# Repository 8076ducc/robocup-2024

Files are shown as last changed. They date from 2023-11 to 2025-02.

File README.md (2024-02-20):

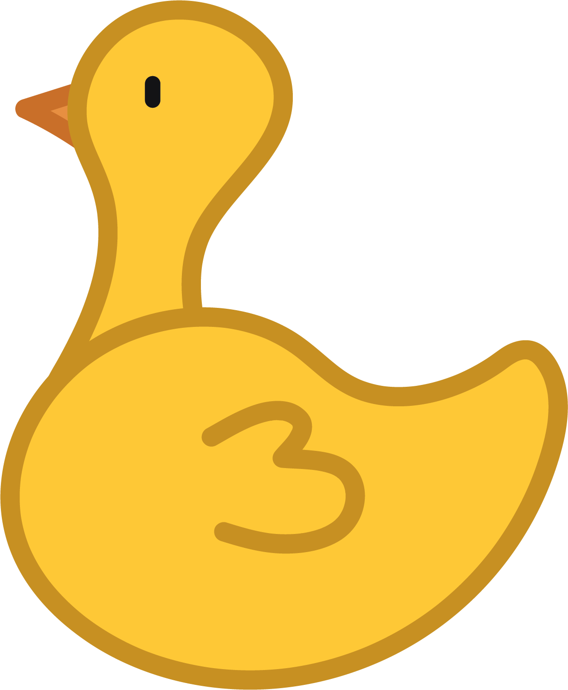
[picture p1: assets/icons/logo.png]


# ducc. Robotics: RoboCupJunior Soccer 2024

This repository contains ducc's working files and source code for the 2024 RoboCupJunior Soccer Open and Soccer Lightweight competition.

## About

ducc is a six-man team comprising Neo Hao Jun, Isaac Tan, Zhu Yunsong, Aidan Yeong, Oliver Zhao, and Ng Aaron from the Hwa Chong Robotics Club in Singapore.

## Technologies

This project was built with the following tools:

- Mechanical: Autodesk Fusion 360
- Electrical: KiCad
- Programming: PlatformIO

## Intellectual Property

### Copyright

© 2023, ducc. Robotics Competition Team.

While we have made every effort to abide by legal and ethical requirements when using works that we did not create, some may have been overlooked inadvertently. Please let us know and we will be happy to make the necessary arrangements.

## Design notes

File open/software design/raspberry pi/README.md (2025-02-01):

1. Get the dt-blob-bin file by running `sudo wget https://datasheets.raspberrypi.com/cmio/dt-blob-dualcam.bin -O /boot/dt-blob.bin` in the terminal.

2. Run `sudo nano /boot/firmware/config.txt` in the terminal, scroll down and add the following lines to the bottom of the file:
```
dtoverlay=imx708,cam0
dtoverlay=imx708,cam1
```

3. Run `libcamera-hello` in the terminal to determine if the cameras are detected.

4. Compile OpenCV from source; follow the guide [here](https://qengineering.eu/install-opencv-on-raspberry-64-os.html).

5. Install LCCV by following the instructions [here](https://github.com/8076ducc/lccv).

6. Create symbolic links by running the following commands in the terminal:
```bash
sudo ln -s /usr/local/include/opencv4/opencv2 /usr/local/include/opencv2
sudo ln -s /usr/include/libcamera/libcamera /usr/local/include/libcamera
```

7. Install wiringpi by following the guide [here](https://github.com/WiringPi/WiringPi).

8. In Geany, manage your build settings and configure it to compile via the following command:
```bash
sudo g++ -Wall -o "%e" "%f" -lopencv_core -lopencv_videoio -lopencv_highgui -lopencv_imgproc -lopencv_video -llccv -lwiringPi
```

9. Test Geany compilation by pressing the brown brick button in your desired file (e.g. `tracker.cpp`; don't compile in `threads.h` or some other header file) THEN run the code by clicking the airplane symbol. You may wish to use the function row keyboard shortcuts at your convenience.

10. Transfer the two files in the `systemctl` folder in this repository to the `/lib/systemd/system` folder on the Raspberry Pi.

11. Individually check that the services are working using the following commands:
```bash
sudo systemctl start configure-gpio.service
sudo systemctl status configure-gpio.service
sudo systemctl stop configure-gpio.service

sudo systemctl start tracker.service
sudo systemctl status tracker.service
sudo systemctl stop tracker.service
```

12. Enable both services to run on startup using the following commands:
```bash
sudo systemctl enable configure-gpio.service
sudo systemctl enable tracker.service
```

13. Run `sudo systemctl disable NetworkManager-wait-online.service` in the terminal.

Other notes:
- DO NOT 千万不要 plug or unplug the camera module while power is still connected. Shut the RPi down and unplug all power cables before doing anything with the camera module.
- Placing everything in the Desktop is a personal decision I made so that it's more convenient for me to open files when I VNC into the RPi. You might want to pull the entire repository directly into the RPi (I highly recomend that); in which case you should change the directories to the executables in the `configure-gpio.service` and `tracker.service` files.

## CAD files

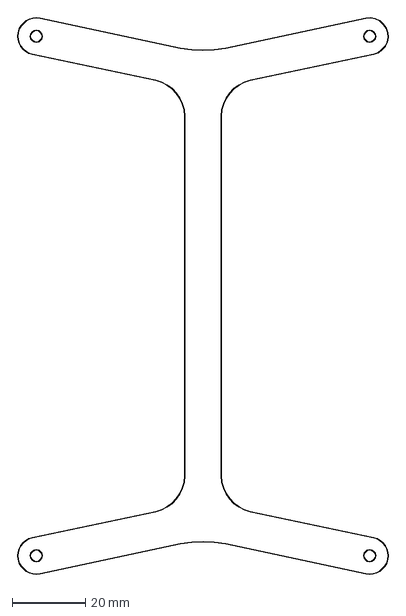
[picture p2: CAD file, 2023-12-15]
open/mechanical design/plates/handle/full drawing.dxf
101.7 x 152.3 mm

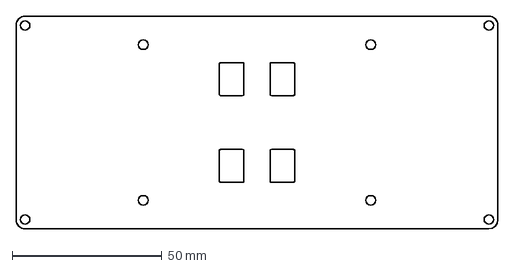
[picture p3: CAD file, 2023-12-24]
open/mechanical design/plates/layer 2.5/full drawing.dxf
161.0 x 71.0 mm

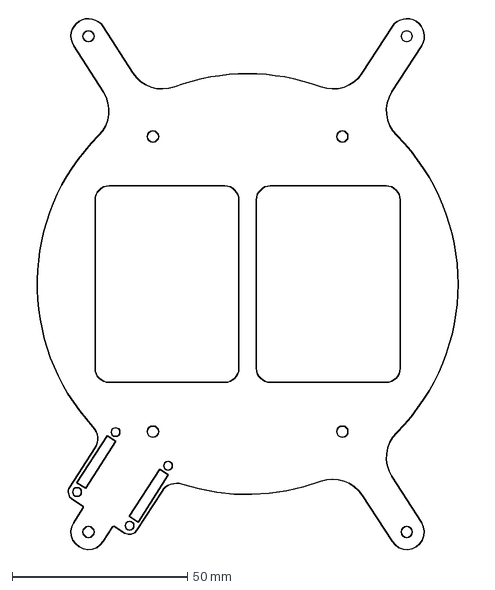
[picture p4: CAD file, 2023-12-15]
open/mechanical design/plates/layer 5/full drawing.dxf
131.8 x 152.2 mm

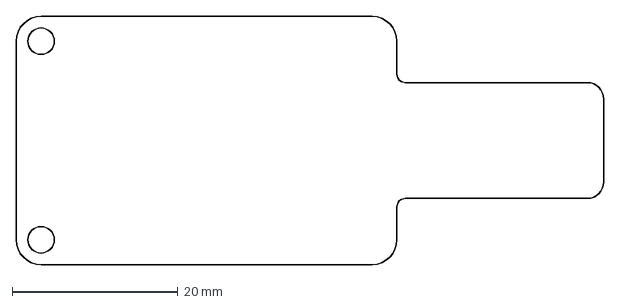
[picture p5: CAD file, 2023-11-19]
open/mechanical design/plates/driver/full outline.dxf
71.0 x 30.0 mm

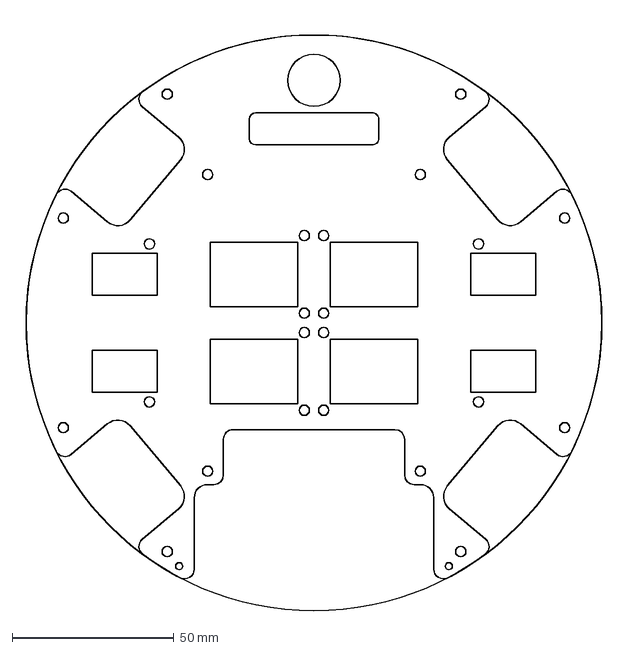
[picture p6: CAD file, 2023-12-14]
open/mechanical design/plates/layer 2/full drawing.dxf
184.2 x 183.8 mm

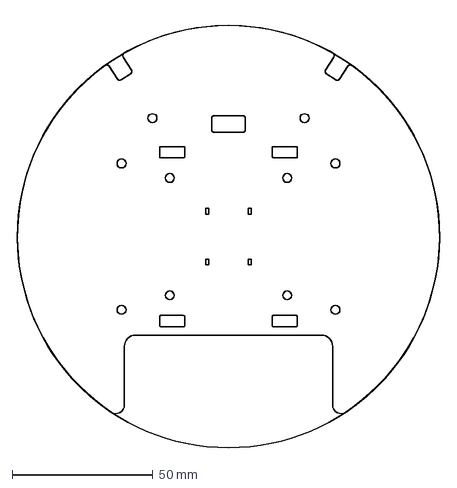
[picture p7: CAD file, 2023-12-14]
open/mechanical design/plates/layer 3/full drawing.dxf
150.9 x 153.3 mm

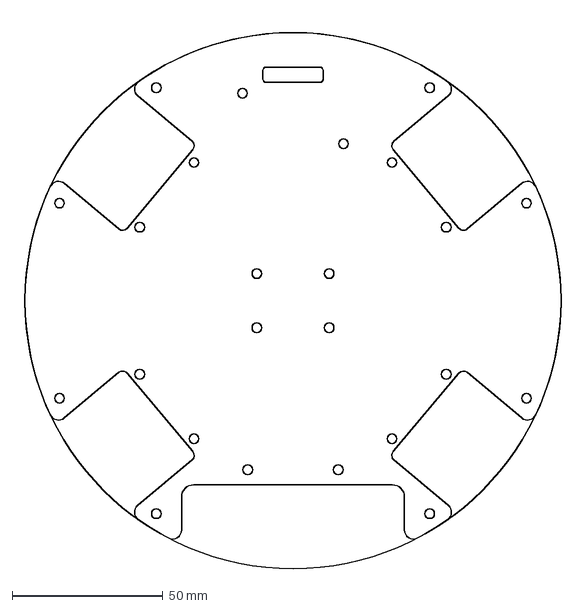
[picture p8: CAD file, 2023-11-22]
open/mechanical design/plates/layer 1/full drawing.dxf
183.7 x 183.4 mm

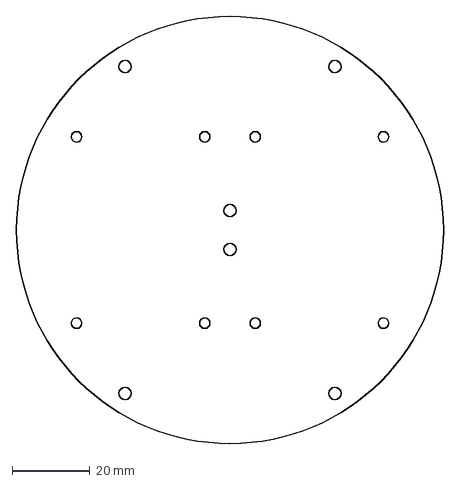
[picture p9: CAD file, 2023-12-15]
open/mechanical design/plates/layer 4/full drawing.dxf
110.0 x 110.0 mm

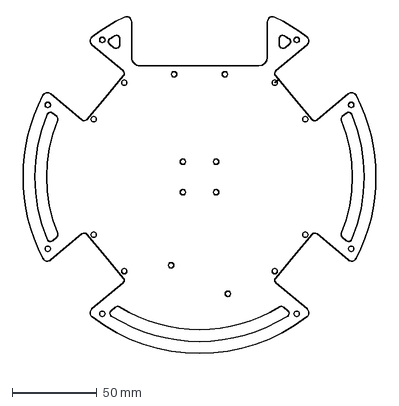
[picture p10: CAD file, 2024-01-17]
lightweight/layer1/lw layer1.dxf
215.8 x 205.7 mm

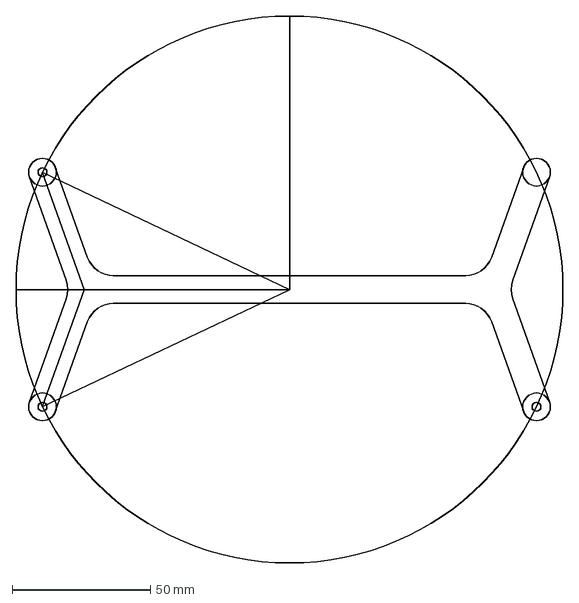
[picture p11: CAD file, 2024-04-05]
lightweight/lw handle.dxf
198.0 x 198.0 mm

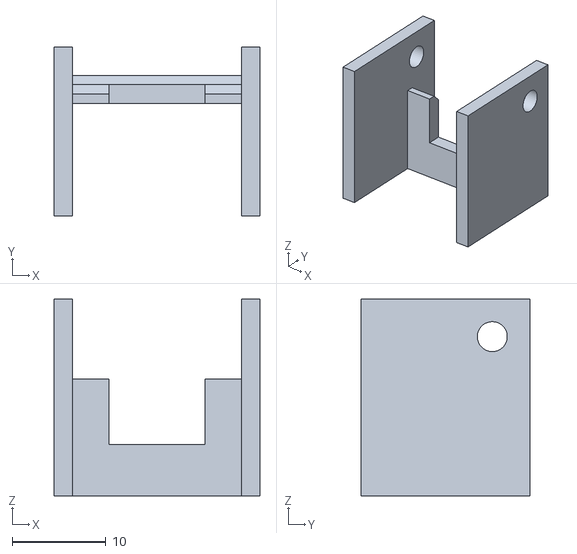
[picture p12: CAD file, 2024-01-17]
mechanical design/dribbler/sillicone valley (10mm).stl
22.0 x 18.0 x 21.0

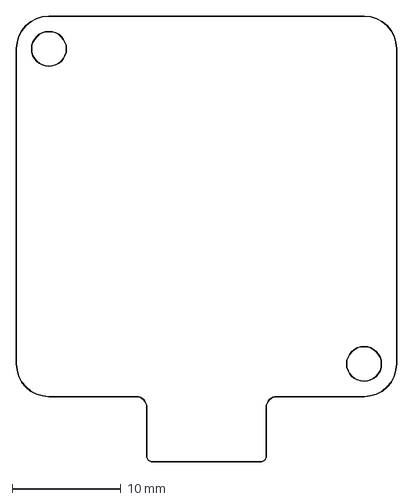
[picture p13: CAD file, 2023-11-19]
mechanical design/plates/driver.dxf
35.0 x 41.0 mm

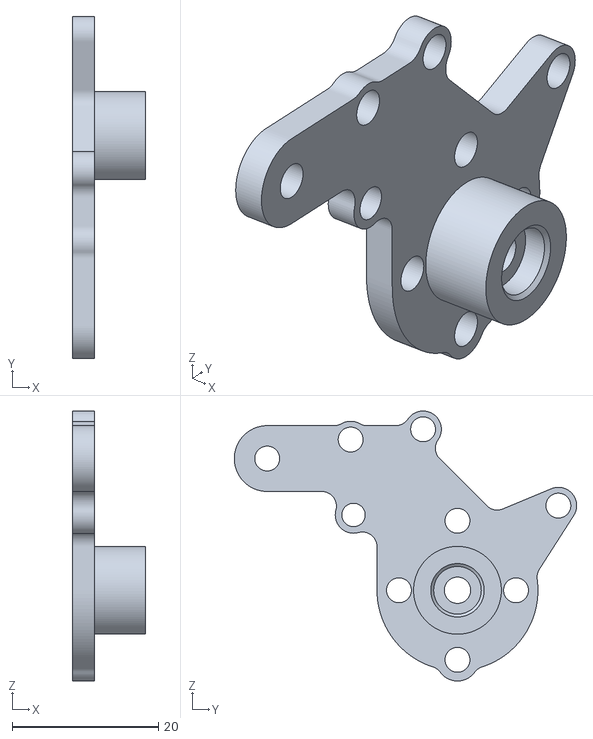
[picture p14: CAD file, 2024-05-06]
open/mechanical design/ball puncher/plate (left).stl
10.0 x 46.8 x 36.9

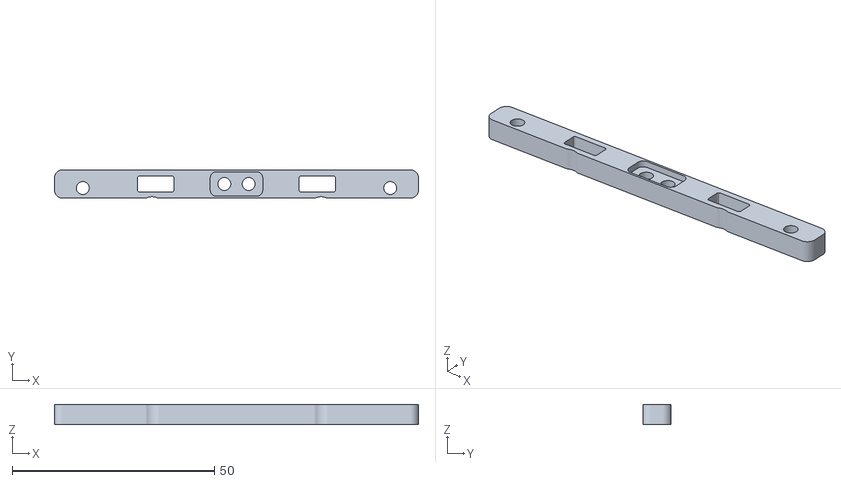
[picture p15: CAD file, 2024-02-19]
open/mechanical design/battery plate adapter/battery plate adapter.stl
90.0 x 7.00 x 5.00

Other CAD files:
open/mechanical design/camera/raspi spacer.stl
open/mechanical design/cycloidal drive/gearbox cover.stl
open/mechanical design/dribbler/dribbler mount.stl
open/mechanical design/dribbler/mould/big mould.stl
mechanical design/dribbler/dribbler mount v29.stl
mechanical design/dribbler/dribbler mount.stl
mechanical design/dribbler/gear cover.stl
mechanical design/dribbler/gear shield (3mm gear).stl
mechanical design/dribbler/gear shield (5mm gear).stl
mechanical design/dribbler/kicker plate v6.stl
mechanical design/dribbler/plate (right).stl
mechanical design/dribbler/ramp.stl
mechanical design/dribbler/roller (left).stl
mechanical design/dribbler/roller (right).stl
mechanical design/dribbler/roller cover.stl
mechanical design/dribbler/silicone valley (big).stl
mechanical design/dribbler/silicone valley (small).stl
mechanical design/dribbler/spacer.stl
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

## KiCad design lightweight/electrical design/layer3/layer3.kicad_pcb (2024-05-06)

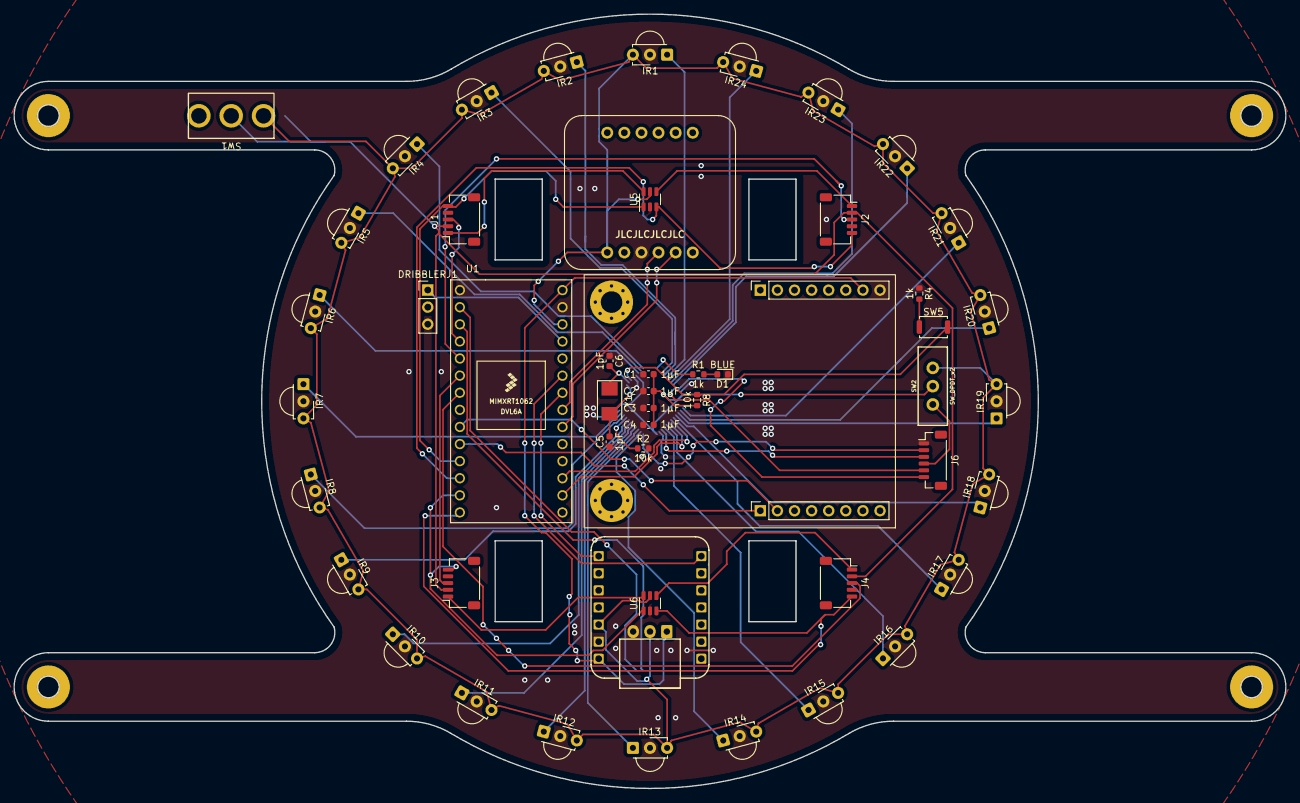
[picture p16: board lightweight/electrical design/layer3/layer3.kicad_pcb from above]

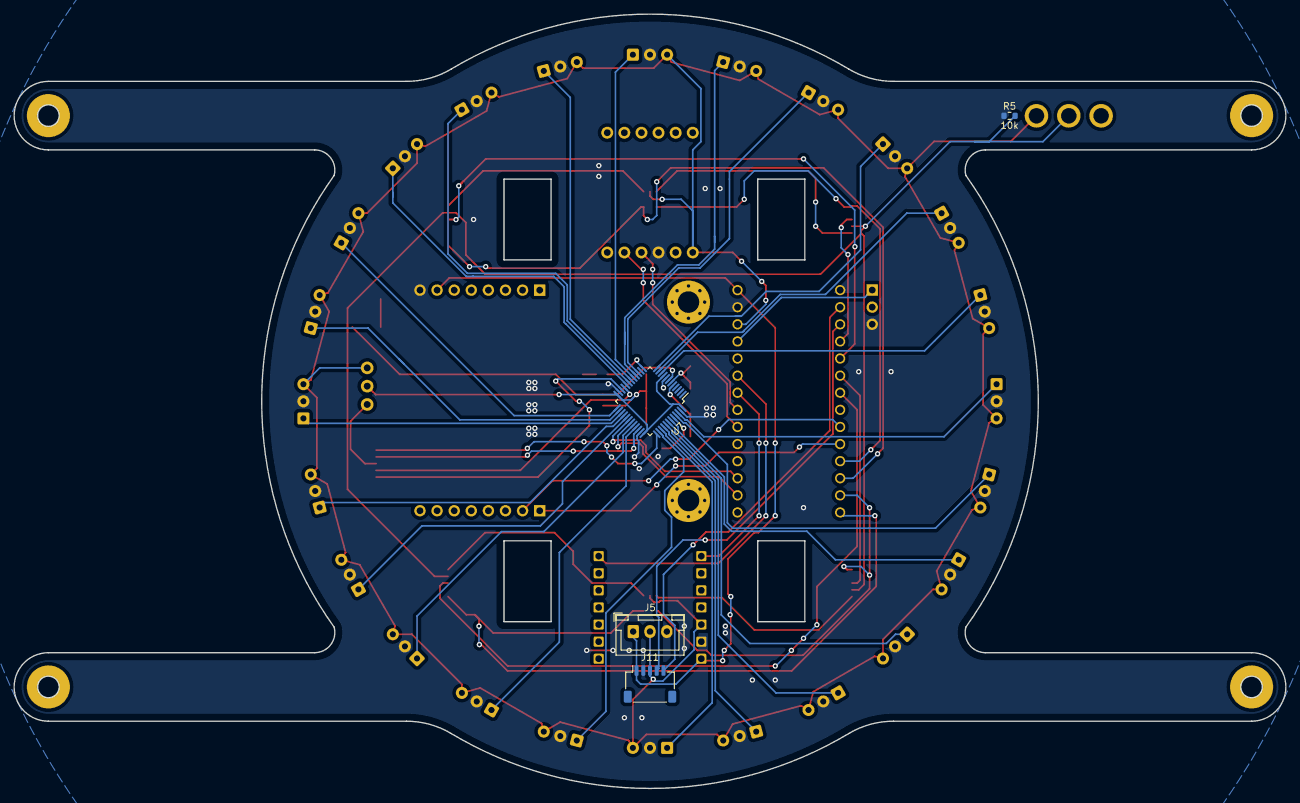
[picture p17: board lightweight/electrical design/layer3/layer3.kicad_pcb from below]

Board: 2 copper layers, 188.9 x 115.0 mm, 59 parts (4 on the bottom side), 64 nets.

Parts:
C1, C2, C3, C4: 1μF; C_0603_1608Metric
C5, C6: 1pF; C_0603_1608Metric
D1: BLUE; D_0603_1608Metric
DRIBBLERJ1: Conn_01x03_Male; PinHeader_1x03_P2.54mm_Vertical
H1, H2, H3, H4: MountingHole; MountingHole_3.2mm_M3_Pad
IR1, IR2, IR3, IR4, IR5, IR6, IR7, IR8, IR9, IR10, IR11, IR12, IR13, IR14, IR15, IR16, IR17, IR18, IR19, IR20, IR21, IR22, IR23, IR24: TSSP58038; Vishay_MINICAST-3Pin
J1, J2, J3, J4, J11: SH1.0 5P; JST_SH_SM05B-SRSS-TB_1x05-1MP_P1.00mm_Horizontal
J5: Conn_01x03_Pin; JST_XH_B3B-XH-A_1x03_P2.50mm_Vertical
J6: SH1.0 Female; JST_SH_BM06B-SRSS-TB_1x06-1MP_P1.00mm_Vertical
R1, R4: 1k; R_0603_1608Metric
R2, R5, R8: 10k; R_0603_1608Metric
SW1: SW_SPDT; SWITCH_SPDT_PTH_12.7X6.7MM
SW2: SW_DPDT_x2; SWITCH_SPDT_PTH_11.6X4.0MM_LOCK
SW5: SW_Push; SW_Push_SPST_NO_Alps_SKRK
U1: TEENSY 4.0; Teensy 4.0
U2: MOUDLE-SEEEDUINO-XIAO-ESP32C3; xiao-esp32c3
U3: Conn_01x16_Socket; openmv
U4: BNO085; bno085
U5, U6: 74LVC2G04; SOT-23-6
U7: STM32F103C8T6; LQFP-48_7x7mm_P0.5mm
Y1: Crystal; Crystal_SMD_5032-2Pin_5.0x3.2mm

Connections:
+3V3: IR1.3 (Vs), IR2.3 (Vs), IR3.3 (Vs), IR4.3 (Vs), IR5.3 (Vs), IR6.3 (Vs), IR7.3 (Vs), IR8.3 (Vs), IR9.3 (Vs), IR10.3 (Vs), IR11.3 (Vs), IR12.3 (Vs), IR13.3 (Vs), IR14.3 (Vs), IR15.3 (Vs), IR16.3 (Vs), IR17.3 (Vs), IR18.3 (Vs), IR19.3 (Vs), IR20.3 (Vs), IR21.3 (Vs), IR22.3 (Vs), IR23.3 (Vs), IR24.3 (Vs), J5.2, J11.3, SW1.1 (A), SW2.1 (A), U1.3.3V_2, U2.12 (3V3), U4.JP1_1 (VIN), U5.5 (VCC), U6.5 (VCC)
+5V: J5.1, J11.1, U1.VIN, U2.14 (5V), U3.10
/BTRX: U1.21, U2.7 (PB08_A6_D6_TX)
/BTTX: U1.20, U2.8 (PB09_A7_D7_RX)
/CAMRX: U1.8, U3.1
/CAMTX: U1.7, U3.2
/DRIBBLERPWM: DRIBBLERJ1.1, U1.23
/EN: J1.2, J2.2, J3.2, J4.2, R5.2, SW1.2 (B)
/IMUSCL: U1.19, U4.JP1_4 (SCL)
/IMUSDA: U1.18, U4.JP1_5 (SDA)
/L1RX: J11.4, U1.1
/L1TX: J11.5, U1.0
/M1INA: J1.5, U1.9, U5.1
/M1INB: J1.1, U5.6
/M1PWM: J1.3, U1.2
/M2INA: J2.5, U1.10, U5.3
/M2INB: J2.1, U5.4
/M2PWM: J2.3, U1.3
/M3INA: J3.5, U1.11, U6.1
/M3INB: J3.1, U6.6
/M3PWM: J3.3, U1.4
/M4INA: J4.5, U1.12, U6.3
/M4INB: J4.1, U6.4
/M4PWM: J4.3, U1.5
/ir/DEBUGRX: J6.6, U7.22 (PB11)
/ir/DEBUGTX: J6.5, U7.21 (PB10)
/ir/IR1: IR1.1 (OUT), U7.17 (PA7)
/ir/IR2: IR2.1 (OUT), U7.16 (PA6)
/ir/IR3: IR3.1 (OUT), U7.15 (PA5)
/ir/IR4: IR4.1 (OUT), U7.12 (PA2)
/ir/IR5: IR5.1 (OUT), U7.11 (PA1)
/ir/IR6: IR6.1 (OUT), U7.10 (PA0)
/ir/IR7: IR7.1 (OUT), U7.46 (PB9)
/ir/IR8: IR8.1 (OUT), U7.45 (PB8)
/ir/IR9: IR9.1 (OUT), U7.43 (PB7)
/ir/IR10: IR10.1 (OUT), U7.42 (PB6)
/ir/IR11: IR11.1 (OUT), U7.41 (PB5)
/ir/IR12: IR12.1 (OUT), U7.40 (PB4)
/ir/IR13: IR13.1 (OUT), U7.39 (PB3)
/ir/IR14: IR14.1 (OUT), U7.38 (PA15)
/ir/IR15: IR15.1 (OUT), U7.33 (PA12)
/ir/IR16: IR16.1 (OUT), U7.32 (PA11)
/ir/IR17: IR17.1 (OUT), U7.29 (PA8)
/ir/IR18: IR18.1 (OUT), U7.28 (PB15)
/ir/IR19: IR19.1 (OUT), U7.27 (PB14)
/ir/IR20: IR20.1 (OUT), U7.26 (PB13)
/ir/IR21: IR21.1 (OUT), U7.25 (PB12)
/ir/IR22: IR22.1 (OUT), U7.20 (PB2)
/ir/IR23: IR23.1 (OUT), U7.19 (PB1)
/ir/IR24: IR24.1 (OUT), U7.18 (PB0)
/ir/MCU3V3: C1.2, C2.2, C3.2, C4.2, R8.2, SW2.2 (B), U7.9 (VDDA), U7.24 (VDD), U7.36 (VDD), U7.48 (VDD)
/ir/OSCIN: C5.2, U7.5 (PD0), Y1.2
/ir/OSCOUT: C6.2, U7.6 (PD1), Y1.1
/ir/PROG3V3: J6.4, SW2.3 (C)
/ir/RESET: R8.1, SW5.2, U7.7 (NRST)
/ir/SWDCLOCK: J6.2, U7.37 (PA14)
/ir/SWDIO: J6.3, U7.34 (PA13)
GND: C1.1, C2.1, C3.1, C4.1, C5.1, C6.1, D1.1 (K), DRIBBLERJ1.3, IR1.2 (GND), IR2.2 (GND), IR3.2 (GND), IR4.2 (GND), IR5.2 (GND), IR6.2 (GND), IR7.2 (GND), IR8.2 (GND), IR9.2 (GND), IR10.2 (GND), IR11.2 (GND), IR12.2 (GND), IR13.2 (GND), IR14.2 (GND), IR15.2 (GND), IR16.2 (GND), IR17.2 (GND), IR18.2 (GND), IR19.2 (GND), IR20.2 (GND), IR21.2 (GND), IR22.2 (GND), IR23.2 (GND), IR24.2 (GND), J5.3, J6.1, J11.2, R2.2, R4.1, R5.1, U1.G1, U1.G3, U2.13 (GND), U3.9, U4.JP1_3 (GND), U5.2 (GND), U6.2 (GND), U7.8 (VSSA), U7.23 (VSS), U7.35 (VSS), U7.47 (VSS)
IRRX: U1.14, U7.31 (PA10)
IRTX: U1.15, U7.30 (PA9)
unnamed: D1.2 (A), R1.2
unnamed: R4.2, SW5.1
unnamed: R2.1, U7.44 (BOOT0)
unnamed: R1.1, U7.13 (PA3)

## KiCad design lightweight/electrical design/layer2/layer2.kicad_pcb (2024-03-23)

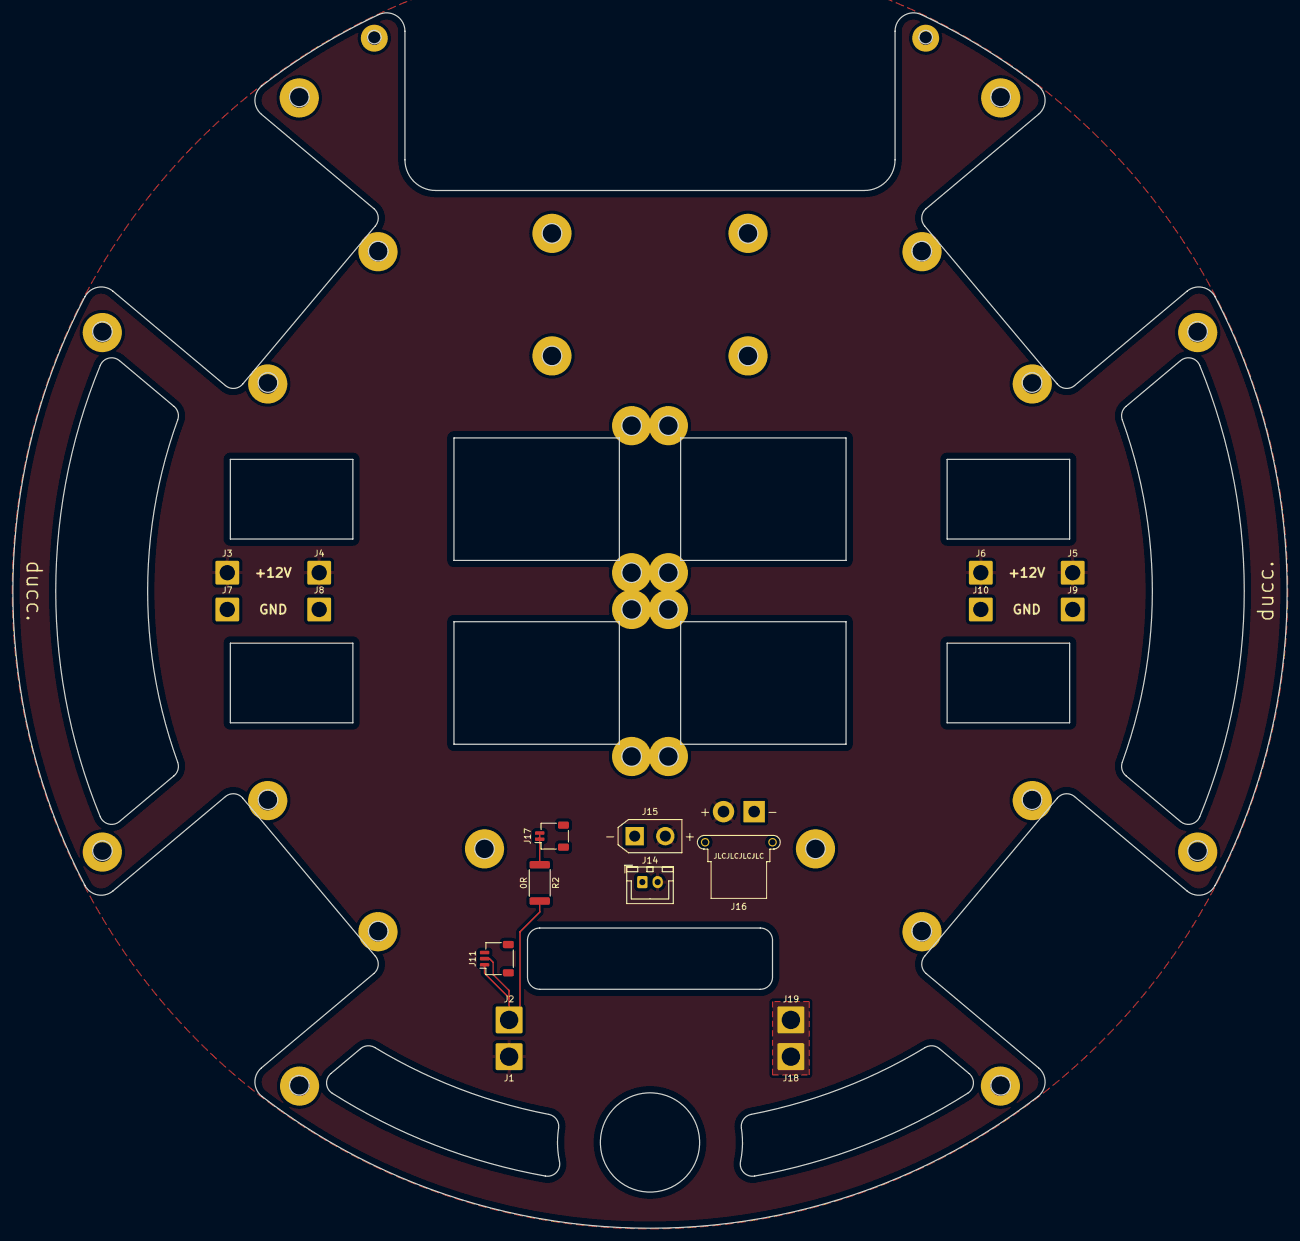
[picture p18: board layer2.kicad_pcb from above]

Board: 2 copper layers, 208.0 x 198.4 mm, 50 parts (0 on the bottom side), 4 nets.

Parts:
H1, H2, H3, H4, H5, H6, H7, H8, H9, H10, H11, H12, H13, H14, H15, H16, H17, H18, H19, H20, H21, H22, H23, H24, H25, H26, H27, H28, H29, H30: MountingHole; MountingHole_3.2mm_M3_Pad
H33, H34: MountingHole; MountingHole_2.2mm_M2_Pad
J1, J2, J18, J19: Conn_01x01_Female; SolderWire-2.5sqmm_1x01_D2.4mm_OD4.4mm
J3, J4, J5, J6, J7, J8, J9, J10: Conn_01x01_Female; SolderWire-2sqmm_1x01_D2mm_OD3.9mm
J11: SH1.0 3P; JST_SH_SM03B-SRSS-TB_1x03-1MP_P1.00mm_Horizontal
J14: XH2.54 2P; JST_XH_B2B-XH-A_1x02_P2.50mm_Vertical
J15: XT30UPB-F; AMASS_XT30UPB-F_1x02_P5.0mm_Vertical
J16: XT30PW-F; AMASS_XT30PW-F_1x02_P2.50mm_Horizontal
J17: SH1.0 2P; JST_SH_SM02B-SRSS-TB_1x02-1MP_P1.00mm_Horizontal
R2: 0R; R_2512_6332Metric

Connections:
+12V: J1.1, J3.1, J4.1, J5.1, J6.1, J14.2, J15.2, J16.2
/BATT: J18.1, J19.1
GND: J2.1, J7.1, J8.1, J9.1, J10.1, J11.1, J11.2, J14.1, J15.1, J16.1, R2.2
unnamed: J17.1, J17.2, R2.1

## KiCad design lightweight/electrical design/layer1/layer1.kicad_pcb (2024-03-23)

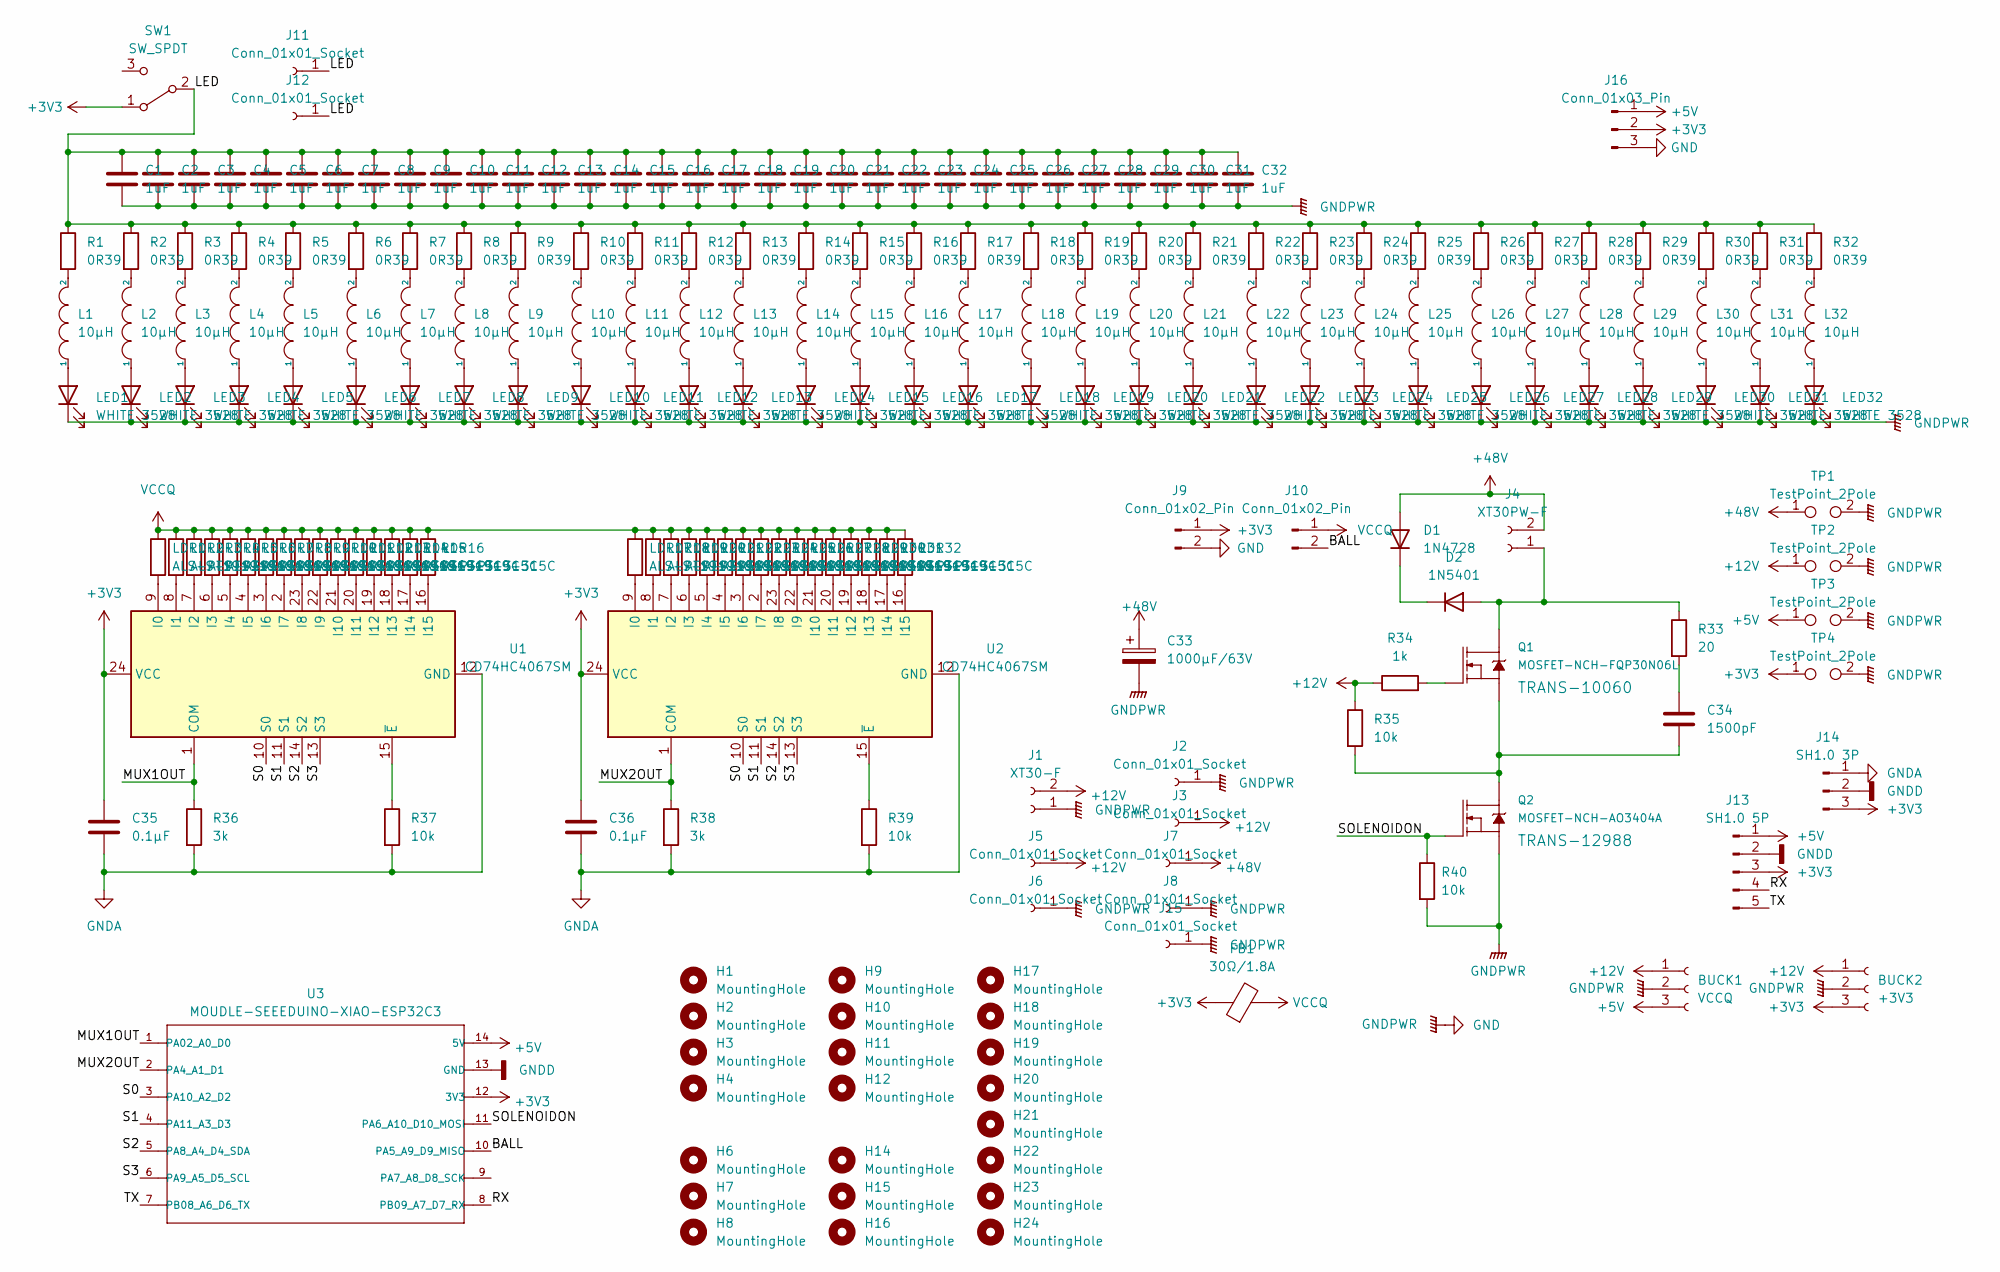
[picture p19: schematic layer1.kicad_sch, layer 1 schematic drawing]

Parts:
BUCK1: VCCQ; PinSocket_1x03_P2.54mm_Horizontal
BUCK2: +3V3; PinSocket_1x03_P2.54mm_Horizontal
C1, C2, C3, C4, C5, C6, C7, C8, C9, C10, C11, C12, C13, C14, C15, C16, C17, C18, C19, C20, C21, C22, C23, C24, C25, C26, C27, C28, C29, C30, C31, C32: 1uF; C_0603_1608Metric
C33: 1000µF/63V; CP_Radial_D16.0mm_P7.50mm
C34: 1500pF; C_0603_1608Metric
C35, C36: 0.1μF; C_0603_1608Metric
D1: 1N4728; D_DO-41_SOD81_P10.16mm_Horizontal
D2: 1N5401; D_DO-27_P15.24mm_Horizontal
FB1: 30Ω/1.8A; C_0603_1608Metric
H1, H2, H3, H4, H6, H7, H8, H9, H10, H11, H12, H14, H15, H16, H17, H18, H19, H20, H21, H22, H23, H24: MountingHole; MountingHole_3.2mm_M3_Pad
J1: XT30-F; AMASS_XT30UPB-F_1x02_P5.0mm_Vertical
J2, J11, J15: Conn_01x01_Socket; SolderWirePad_1x01_SMD_1x2mm
J3, J5, J6, J7, J8: Conn_01x01_Socket; SolderWirePad_1x01_SMD_5x10mm
J4: XT30PW-F; AMASS_XT30UPB-F_1x02_P5.0mm_Vertical
J9, J10: Conn_01x02_Pin; PinHeader_1x02_P2.54mm_Vertical
J12: Conn_01x01_Socket; SolderWire-0.5sqmm_1x01_D0.9mm_OD2.1mm
J13: SH1.0 5P; JST_SH_BM05B-SRSS-TB_1x05-1MP_P1.00mm_Vertical
J14: SH1.0 3P; JST_SH_BM03B-SRSS-TB_1x03-1MP_P1.00mm_Vertical
J16: Conn_01x03_Pin; JST_XH_B3B-XH-A_1x03_P2.50mm_Vertical
L1, L2, L3, L4, L5, L6, L7, L8, L9, L10, L11, L12, L13, L14, L15, L16, L17, L18, L19, L20, L21, L22, L23, L24, L25, L26, L27, L28, L29, L30, L31, L32: 10µH; L_0805_2012Metric
LDR1, LDR2, LDR3, LDR4, LDR5, LDR6, LDR7, LDR8, LDR9, LDR10, LDR11, LDR12, LDR13, LDR14, LDR15, LDR16, LDR17, LDR18, LDR19, LDR20, LDR21, LDR22, LDR23, LDR24, LDR25, LDR26, LDR27, LDR28, LDR29, LDR30, LDR31, LDR32: ALS-PT19-315C; D_0603_1608Metric
LED1, LED2, LED3, LED4, LED5, LED6, LED7, LED8, LED9, LED10, LED11, LED12, LED13, LED14, LED15, LED16, LED17, LED18, LED19, LED20, LED21, LED22, LED23, LED24, LED25, LED26, LED27, LED28, LED29, LED30, LED31, LED32: WHITE 3528; CP_EIA-3528-12_Kemet-T
Q1: MOSFET-NCH-FQP30N06L; TO-220-3_Vertical
Q2: MOSFET-NCH-AO3404A; TSOT-23
R1, R2, R3, R4, R5, R6, R7, R8, R9, R10, R11, R12, R13, R14, R15, R16, R17, R18, R19, R20, R21, R22, R23, R24, R25, R26, R27, R28, R29, R30, R31, R32: 0R39; R_0603_1608Metric
R33: 20; R_0603_1608Metric
R34: 1k; R_0603_1608Metric
R35, R37, R39, R40: 10k; R_0603_1608Metric
R36, R38: 3k; R_0603_1608Metric
SW1: SW_SPDT; SWITCH_SPDT_PTH_11.6X4.0MM
TP1, TP2, TP3, TP4: TestPoint_2Pole; TestPoint_2Pads_Pitch2.54mm_Drill0.8mm
U1, U2: CD74HC4067SM; SOIC-24W_7.5x15.4mm_P1.27mm
U3: MOUDLE-SEEEDUINO-XIAO-ESP32C3; xiao-esp32c3

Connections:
+3V3: BUCK2.3, C35.1, C36.1, FB1.1, J9.1, J13.3, J14.3, J16.2, SW1.1 (A), TP4.1, U1.24 (VCC), U2.24 (VCC), U3.12 (3V3)
+5V: BUCK1.3, J13.1, J16.1, TP3.1, U3.14 (5V)
+12V: BUCK1.1, BUCK2.1, J1.2, J3.1, J5.1, R34.1, R35.1, TP2.1
+48V: C33.1, D1.2 (A), J4.2, J7.1, TP1.1
/BALL: J10.2, U3.10 (PA5_A9_D9_MISO)
/LED: C1.1, C2.1, C3.1, C4.1, C5.1, C6.1, C7.1, C8.1, C9.1, C10.1, C11.1, C12.1, C13.1, C14.1, C15.1, C16.1, C17.1, C18.1, C19.1, C20.1, C21.1, C22.1, C23.1, C24.1, C25.1, C26.1, C27.1, C28.1, C29.1, C30.1, C31.1, C32.1, J11.1, J12.1, R1.1, R2.1, R3.1, R4.1, R5.1, R6.1, R7.1, R8.1, R9.1, R10.1, R11.1, R12.1, R13.1, R14.1, R15.1, R16.1, R17.1, R18.1, R19.1, R20.1, R21.1, R22.1, R23.1, R24.1, R25.1, R26.1, R27.1, R28.1, R29.1, R30.1, R31.1, R32.1, SW1.2 (B)
/MUX1OUT: R36.1, U1.1 (COM), U3.1 (PA02_A0_D0)
/MUX2OUT: R38.1, U2.1 (COM), U3.2 (PA4_A1_D1)
/RX: J13.4, U3.8 (PB09_A7_D7_RX)
/S0: U1.10 (S0), U2.10 (S0), U3.3 (PA10_A2_D2)
/S1: U1.11 (S1), U2.11 (S1), U3.4 (PA11_A3_D3)
/S2: U1.14 (S2), U2.14 (S2), U3.5 (PA8_A4_D4_SDA)
/S3: U1.13 (S3), U2.13 (S3), U3.6 (PA9_A5_D5_SCL)
/SOLENOIDON: Q2.1 (G), R40.1, U3.11 (PA6_A10_D10_MOSI)
/TX: J13.5, U3.7 (PB08_A6_D6_TX)
GND: BUCK1.2, BUCK2.2, C1.2, C2.2, C3.2, C4.2, C5.2, C6.2, C7.2, C8.2, C9.2, C10.2, C11.2, C12.2, C13.2, C14.2, C15.2, C16.2, C17.2, C18.2, C19.2, C20.2, C21.2, C22.2, C23.2, C24.2, C25.2, C26.2, C27.2, C28.2, C29.2, C30.2, C31.2, C32.2, C33.2, J1.1, J2.1, J6.1, J8.1, J9.2, J15.1, J16.3, LED1.1 (K), LED2.1 (K), LED3.1 (K), LED4.1 (K), LED5.1 (K), LED6.1 (K), LED7.1 (K), LED8.1 (K), LED9.1 (K), LED10.1 (K), LED11.1 (K), LED12.1 (K), LED13.1 (K), LED14.1 (K), LED15.1 (K), LED16.1 (K), LED17.1 (K), LED18.1 (K), LED19.1 (K), LED20.1 (K), LED21.1 (K), LED22.1 (K), LED23.1 (K), LED24.1 (K), LED25.1 (K), LED26.1 (K), LED27.1 (K), LED28.1 (K), LED29.1 (K), LED30.1 (K), LED31.1 (K), LED32.1 (K), Q2.2 (S), R40.2, TP1.2, TP2.2, TP3.2, TP4.2
GNDA: C35.2, C36.2, J14.1, R36.2, R37.2, R38.2, R39.2, U1.12 (GND), U2.12 (GND)
GNDD: J13.2, J14.2, U3.13 (GND)
unnamed: C34.1, R33.2
unnamed: D1.1 (K), D2.1 (K)
unnamed: D2.2 (A), J4.1, Q1.2 (D), R33.1
unnamed: L1.2, R1.2
unnamed: L2.2, R2.2
unnamed: L3.2, R3.2
unnamed: L4.2, R4.2
unnamed: L5.2, R5.2
unnamed: L6.2, R6.2
unnamed: L7.2, R7.2
unnamed: L8.2, R8.2
unnamed: L9.2, R9.2
unnamed: L10.2, R10.2
unnamed: L11.2, R11.2
unnamed: L12.2, R12.2
unnamed: L13.2, R13.2
unnamed: L14.2, R14.2
unnamed: L15.2, R15.2
unnamed: L16.2, R16.2
unnamed: L17.2, R17.2
unnamed: L18.2, R18.2
unnamed: L19.2, R19.2
unnamed: L20.2, R20.2
unnamed: L21.2, R21.2
unnamed: L22.2, R22.2
unnamed: L23.2, R23.2
unnamed: L24.2, R24.2
unnamed: L25.2, R25.2
unnamed: L26.2, R26.2
unnamed: L27.2, R27.2
unnamed: L28.2, R28.2
unnamed: L29.2, R29.2
unnamed: L30.2, R30.2
unnamed: L31.2, R31.2
unnamed: L32.2, R32.2
unnamed: L1.1, LED1.2 (A)
unnamed: L2.1, LED2.2 (A)
unnamed: L3.1, LED3.2 (A)
unnamed: L4.1, LED4.2 (A)
unnamed: L5.1, LED5.2 (A)
unnamed: L6.1, LED6.2 (A)
unnamed: L7.1, LED7.2 (A)
unnamed: L8.1, LED8.2 (A)
unnamed: L9.1, LED9.2 (A)
unnamed: L10.1, LED10.2 (A)
unnamed: L11.1, LED11.2 (A)
unnamed: L12.1, LED12.2 (A)
unnamed: L13.1, LED13.2 (A)
unnamed: L14.1, LED14.2 (A)
unnamed: L15.1, LED15.2 (A)
unnamed: L16.1, LED16.2 (A)
unnamed: L17.1, LED17.2 (A)
unnamed: L18.1, LED18.2 (A)
unnamed: L19.1, LED19.2 (A)
unnamed: L20.1, LED20.2 (A)
unnamed: L21.1, LED21.2 (A)
unnamed: L22.1, LED22.2 (A)
unnamed: L23.1, LED23.2 (A)
unnamed: L24.1, LED24.2 (A)
unnamed: L25.1, LED25.2 (A)
unnamed: L26.1, LED26.2 (A)
unnamed: L27.1, LED27.2 (A)
unnamed: L28.1, LED28.2 (A)
unnamed: L29.1, LED29.2 (A)
unnamed: L30.1, LED30.2 (A)
unnamed: L31.1, LED31.2 (A)
unnamed: L32.1, LED32.2 (A)
unnamed: Q1.1 (G), R34.2
unnamed: C34.2, Q1.3 (S), Q2.3 (D), R35.2
unnamed: LDR1.2, U1.9 (I0)
unnamed: LDR2.2, U1.8 (I1)
unnamed: LDR3.2, U1.7 (I2)
unnamed: LDR4.2, U1.6 (I3)
unnamed: LDR5.2, U1.5 (I4)
unnamed: LDR6.2, U1.4 (I5)
unnamed: LDR7.2, U1.3 (I6)
unnamed: LDR8.2, U1.2 (I7)
unnamed: LDR9.2, U1.23 (I8)
unnamed: LDR10.2, U1.22 (I9)
unnamed: LDR11.2, U1.21 (I10)
unnamed: LDR12.2, U1.20 (I11)
unnamed: LDR13.2, U1.19 (I12)
unnamed: LDR14.2, U1.18 (I13)
unnamed: LDR15.2, U1.17 (I14)
unnamed: LDR16.2, U1.16 (I15)
unnamed: R37.1, U1.15 (~E)
unnamed: LDR17.2, U2.9 (I0)
unnamed: LDR18.2, U2.8 (I1)
unnamed: LDR19.2, U2.7 (I2)
unnamed: LDR20.2, U2.6 (I3)
unnamed: LDR21.2, U2.5 (I4)
unnamed: LDR22.2, U2.4 (I5)
unnamed: LDR23.2, U2.3 (I6)
unnamed: LDR24.2, U2.2 (I7)
unnamed: LDR25.2, U2.23 (I8)
unnamed: LDR26.2, U2.22 (I9)
unnamed: LDR27.2, U2.21 (I10)
unnamed: LDR28.2, U2.20 (I11)
unnamed: LDR29.2, U2.19 (I12)
unnamed: LDR30.2, U2.18 (I13)
unnamed: LDR31.2, U2.17 (I14)
unnamed: LDR32.2, U2.16 (I15)
unnamed: R39.1, U2.15 (~E)
VCCQ: FB1.2, J10.1, LDR1.1, LDR2.1, LDR3.1, LDR4.1, LDR5.1, LDR6.1, LDR7.1, LDR8.1, LDR9.1, LDR10.1, LDR11.1, LDR12.1, LDR13.1, LDR14.1, LDR15.1, LDR16.1, LDR17.1, LDR18.1, LDR19.1, LDR20.1, LDR21.1, LDR22.1, LDR23.1, LDR24.1, LDR25.1, LDR26.1, LDR27.1, LDR28.1, LDR29.1, LDR30.1, LDR31.1, LDR32.1

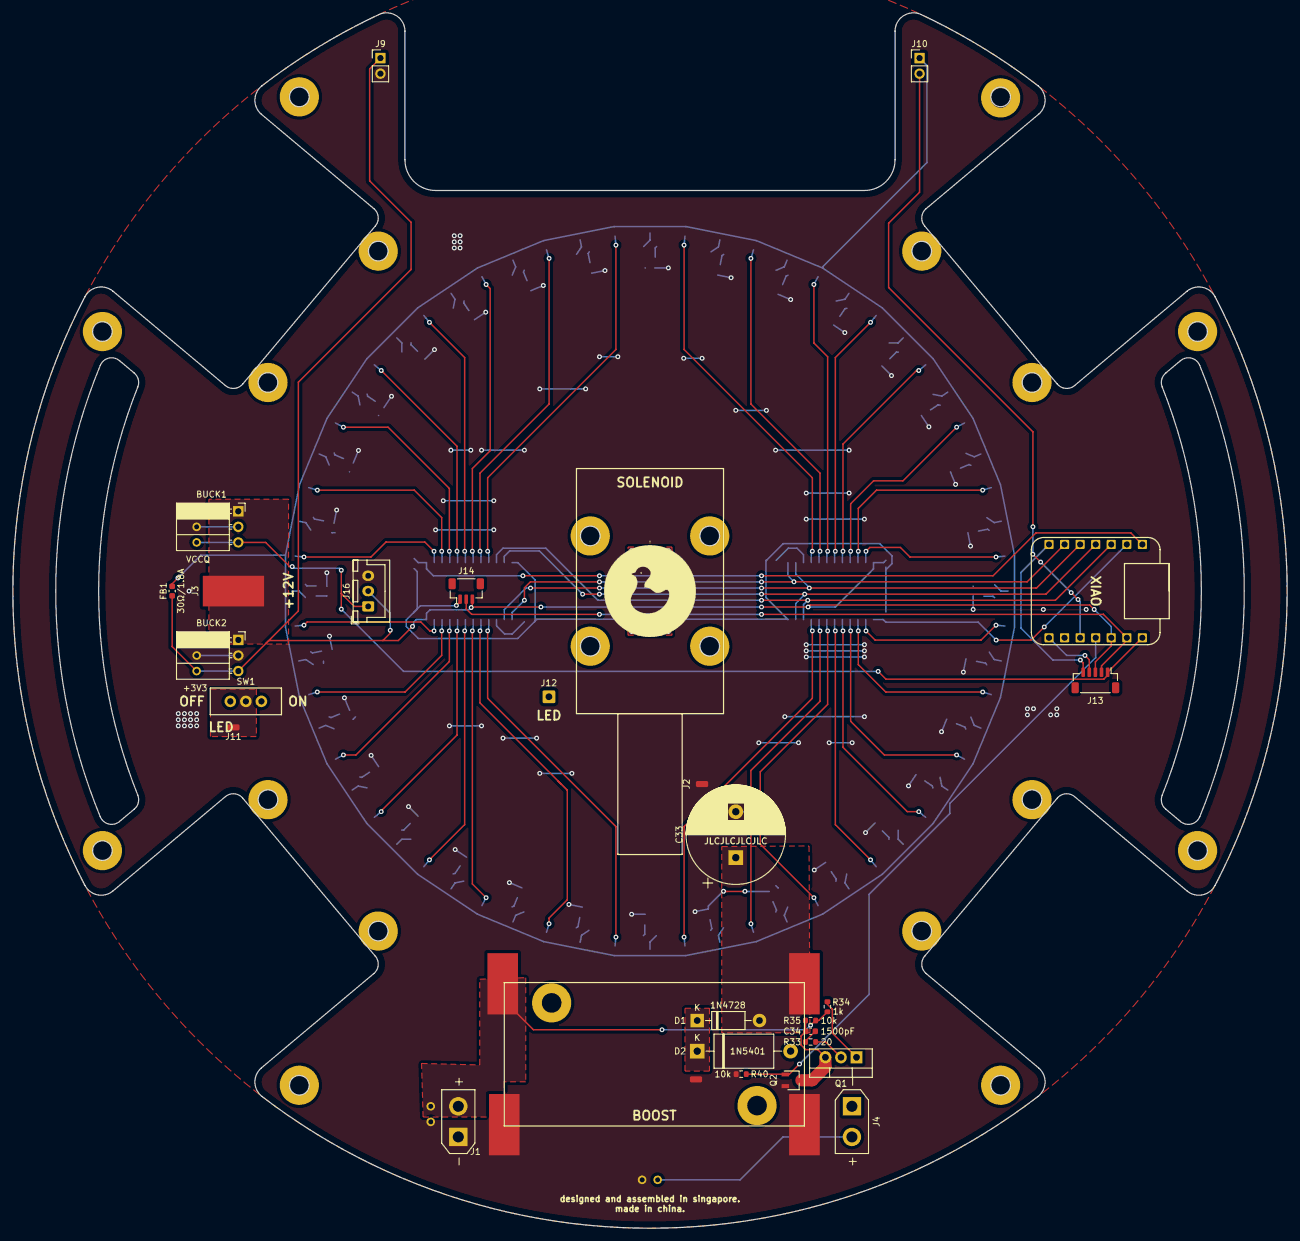
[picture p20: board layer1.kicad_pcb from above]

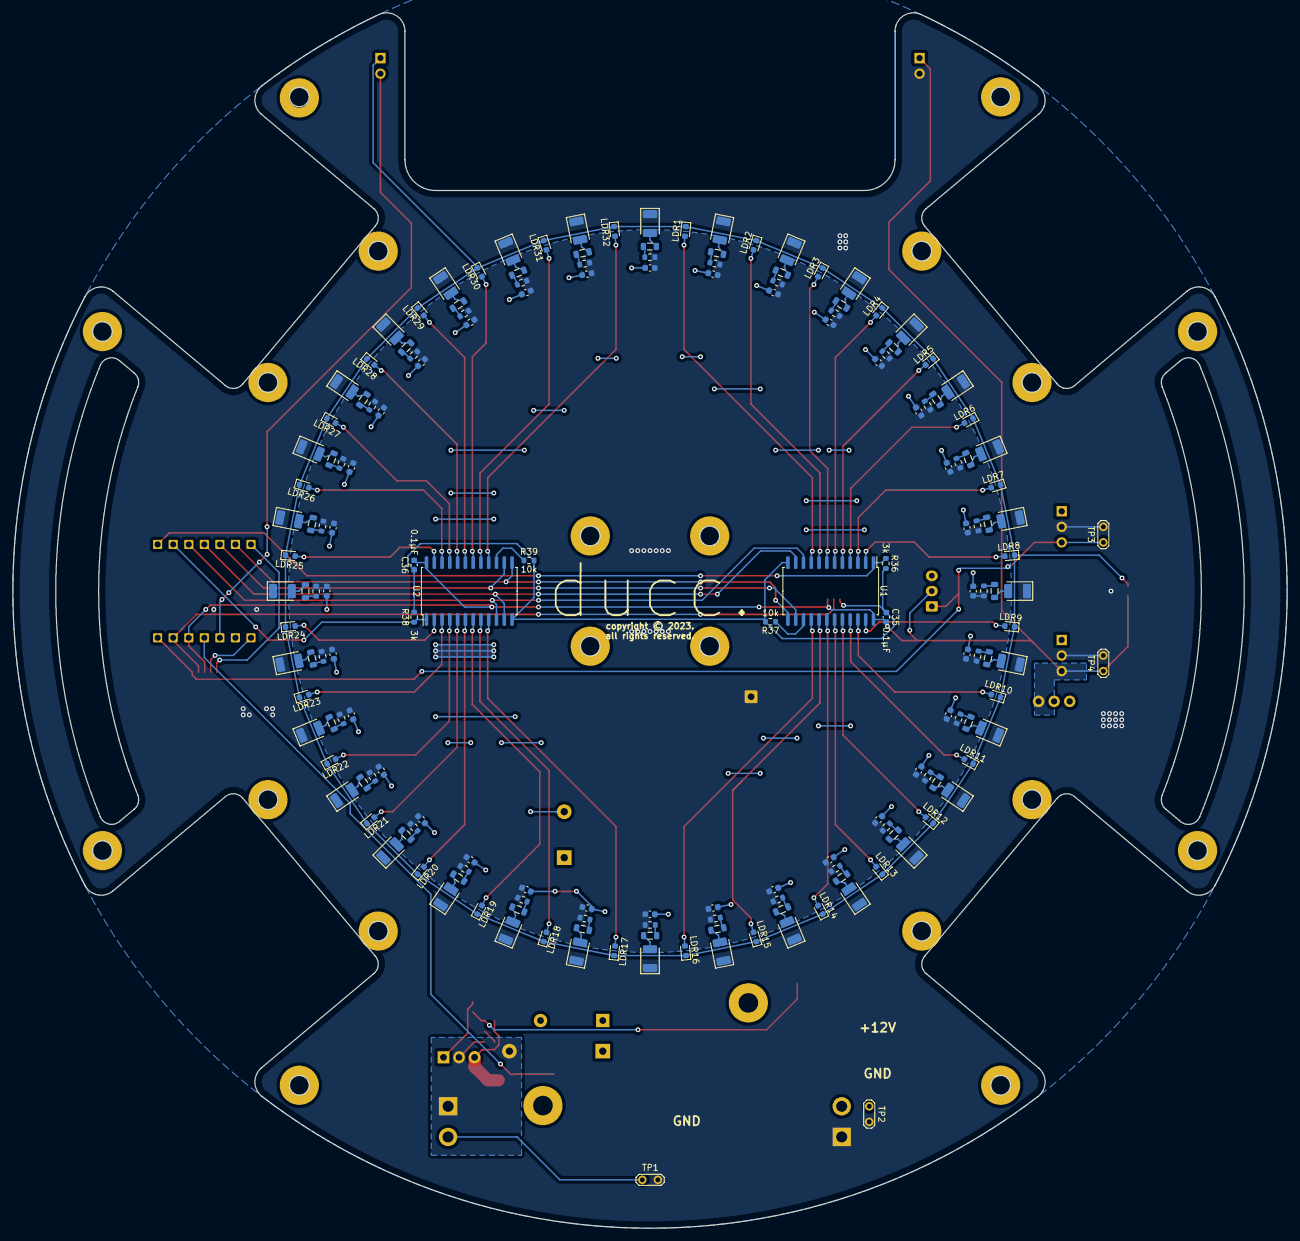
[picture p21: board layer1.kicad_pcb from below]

Board: 2 copper layers, 208.0 x 198.4 mm, 225 parts (172 on the bottom side), 122 nets.

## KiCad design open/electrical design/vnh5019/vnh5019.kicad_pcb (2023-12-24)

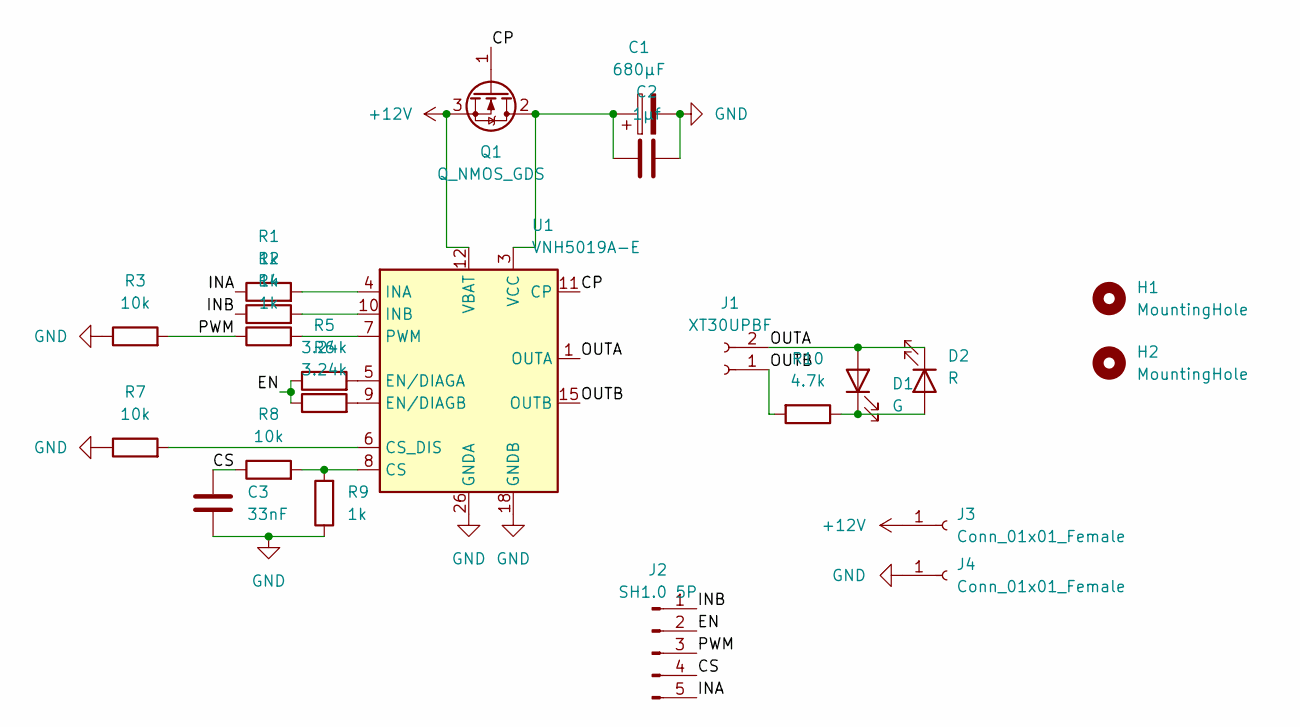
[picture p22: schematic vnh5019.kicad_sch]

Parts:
C1: 680µF; CP_Radial_D8.0mm_P3.50mm
C2: 1µf; C_0603_1608Metric
C3: 33nF; C_0603_1608Metric
D1: G; D_0603_1608Metric
D2: R; D_0603_1608Metric
H1, H2: MountingHole; MountingHole_3.2mm_M3_Pad
J1: XT30UPBF; AMASS_XT30UPB-F_1x02_P5.0mm_Vertical
J2: SH1.0 5P; JST_SH_SM05B-SRSS-TB_1x05-1MP_P1.00mm_Horizontal
J3, J4: Conn_01x01_Female; SolderWirePad_1x01_SMD_5x10mm
Q1: Q_NMOS_GDS; TO-252-2
R1, R2, R4, R9: 1k; R_0603_1608Metric
R3, R7, R8: 10k; R_0603_1608Metric
R5, R6: 3.24k; R_0603_1608Metric
R10: 4.7k; R_0603_1608Metric
U1: VNH5019A-E; ST_MultiPowerSO-30

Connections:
+12V: J3.1, Q1.3 (S), U1.12 (VBAT)
/CP: Q1.1 (G), U1.11 (CP)
/CS: C3.1, J2.4, R8.1
/EN: J2.2, R5.1, R6.1
/INA: J2.5, R1.1
/INB: J2.1, R2.1
/OUTA: D1.2 (A), D2.1 (K), J1.2, U1.1 (OUTA), U1.25 (OUTA), U1.30 (OUTA), U1.33 (OUTA)
/OUTB: J1.1, R10.2, U1.15 (OUTB), U1.16 (OUTB), U1.21 (OUTB), U1.32 (OUTB)
/PWM: J2.3, R3.2, R4.1
GND: C1.2, C2.2, C3.2, J4.1, R3.1, R7.1, R9.1, U1.18 (GNDB), U1.19 (GNDB), U1.20 (GNDB), U1.26 (GNDA), U1.27 (GNDA), U1.28 (GNDA)
unnamed: D1.1 (K), D2.2 (A), R10.1
unnamed: C1.1, C2.1, Q1.2 (D), U1.3 (VCC), U1.13 (VCC), U1.23 (VCC), U1.31 (VCC)
unnamed: R8.2, R9.2, U1.8 (CS)
unnamed: R7.2, U1.6 (CS_DIS)
unnamed: R5.2, U1.5 (EN/DIAGA)
unnamed: R6.2, U1.9 (EN/DIAGB)
unnamed: R1.2, U1.4 (INA)
unnamed: R2.2, U1.10 (INB)
unnamed: R4.2, U1.7 (PWM)

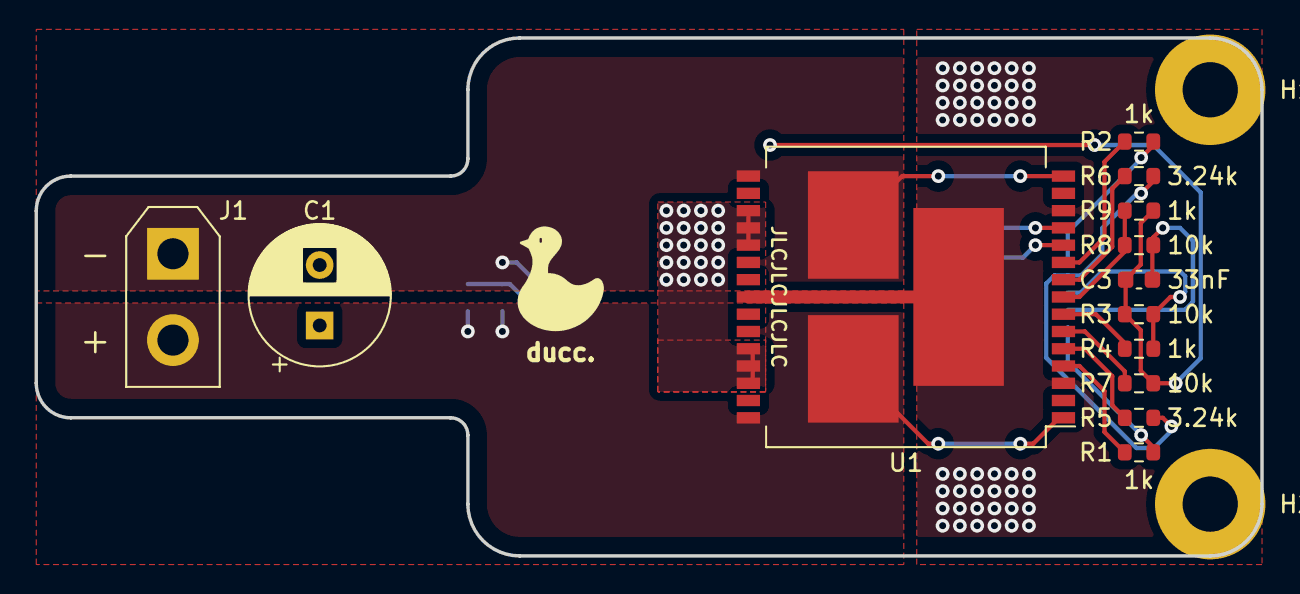
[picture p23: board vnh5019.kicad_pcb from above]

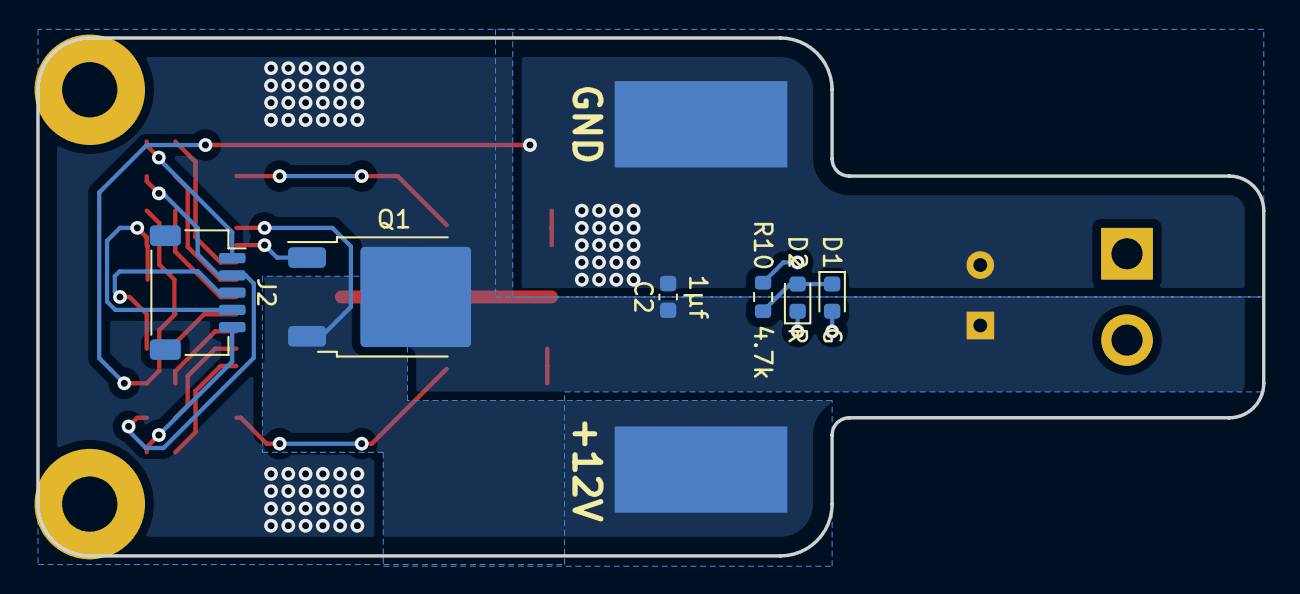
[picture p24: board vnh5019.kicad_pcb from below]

Board: 2 copper layers, 71.0 x 30.0 mm, 23 parts (8 on the bottom side), 19 nets.

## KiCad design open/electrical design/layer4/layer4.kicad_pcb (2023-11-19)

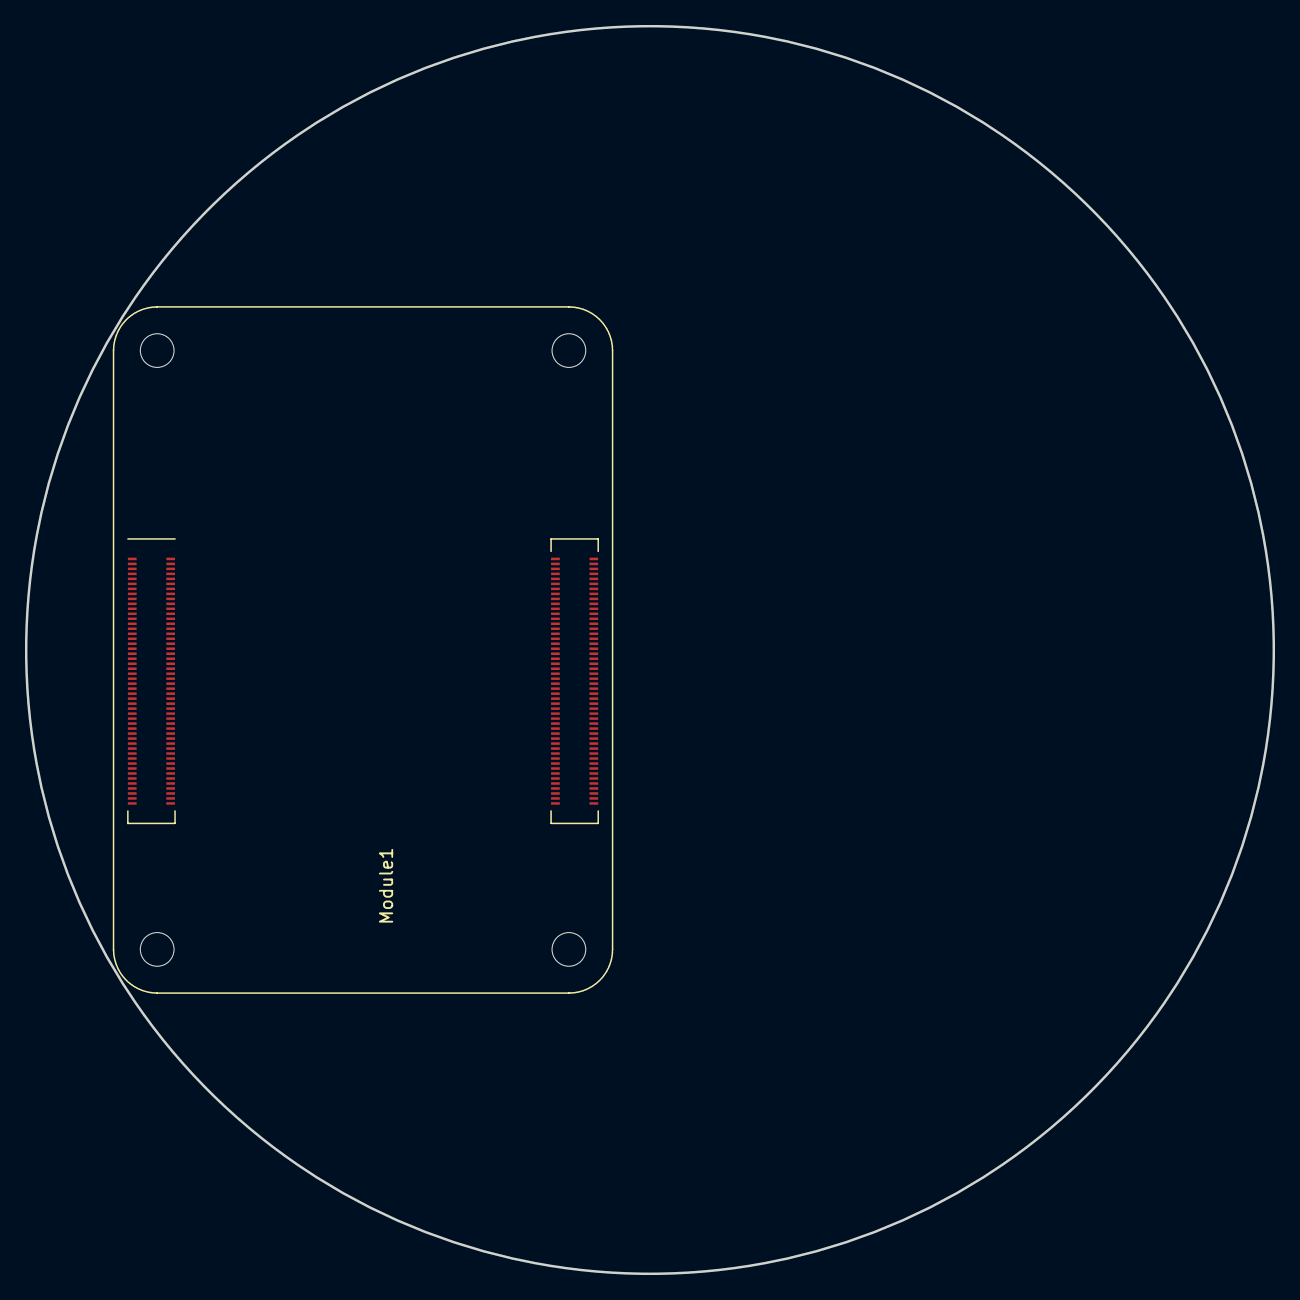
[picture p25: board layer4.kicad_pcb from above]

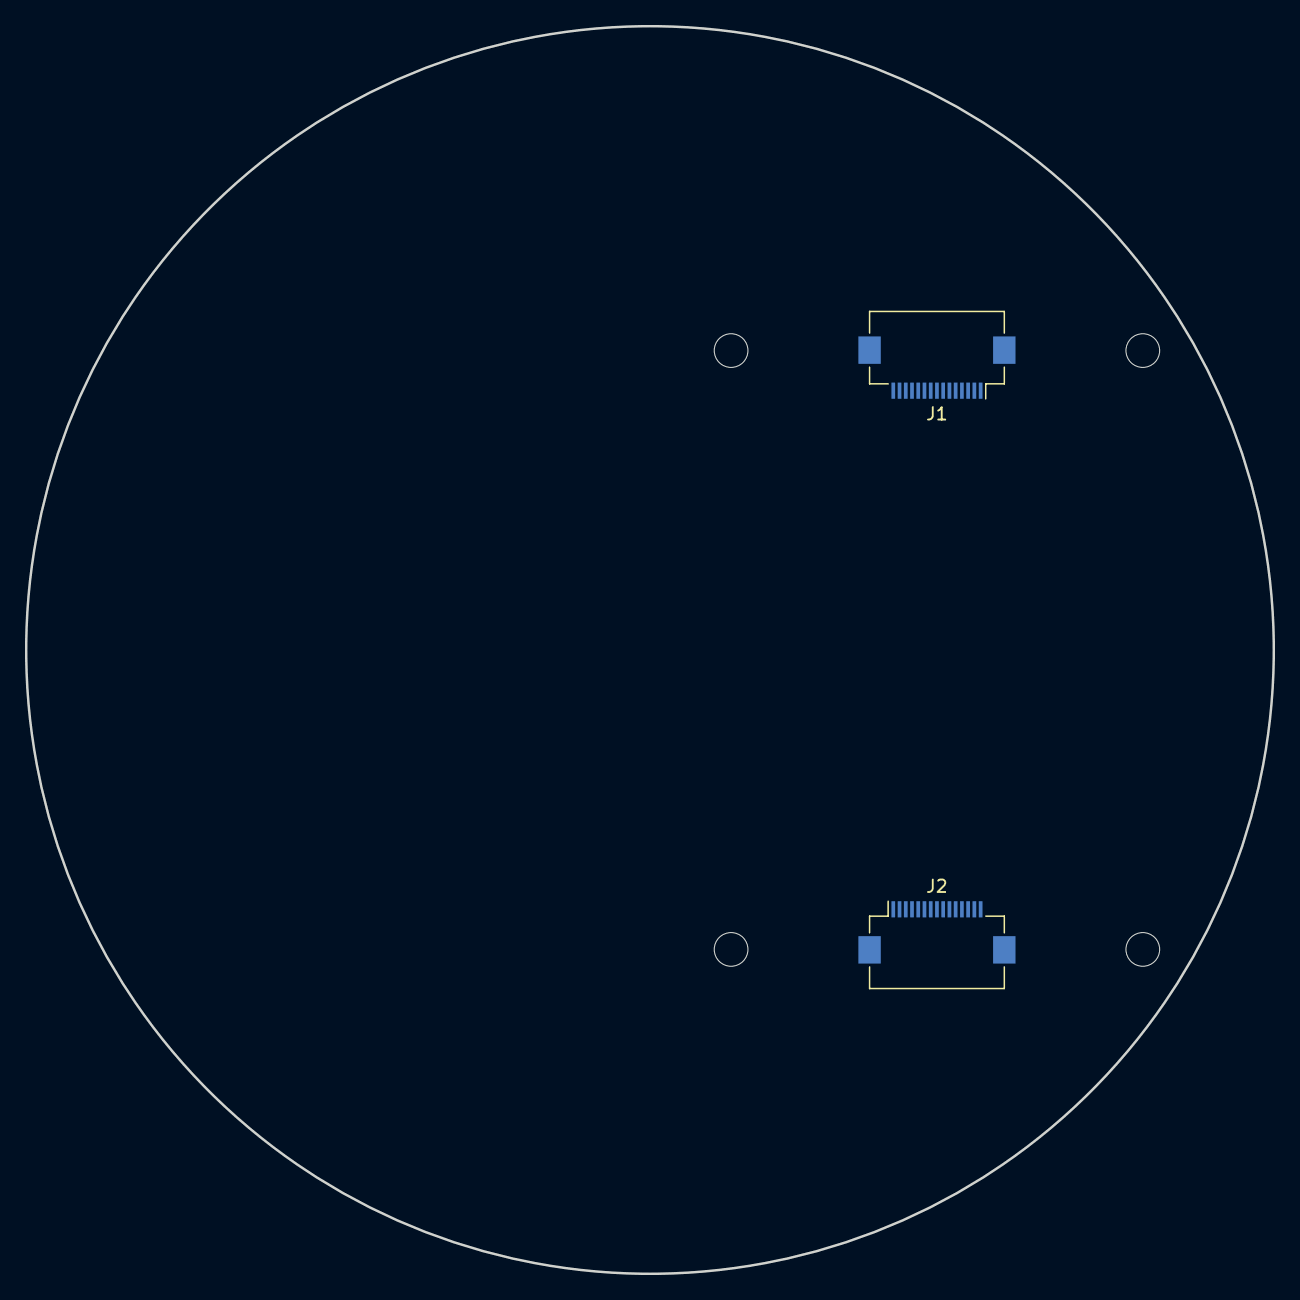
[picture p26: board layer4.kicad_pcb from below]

Board: 2 copper layers, 100.0 x 100.0 mm, 3 parts (2 on the bottom side), 20 nets, no tracks yet.

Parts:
J1, J2: Conn_01x15_Female; Hirose_FH12-15S-0.5SH_1x15-1MP_P0.50mm_Horizontal
Module1: ComputeModule4-CM4; Raspberry-Pi-4-Compute-Module

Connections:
+3V3: J1.15, J2.15, Module1.78 (GPIO_VREF(1.8v/3.3v_Input)), Module1.84 (+3.3v_(Output)), Module1.86 (+3.3v_(Output))
+5V: Module1.77 (+5v_(Input)), Module1.79 (+5v_(Input)), Module1.81 (+5v_(Input)), Module1.83 (+5v_(Input)), Module1.85 (+5v_(Input)), Module1.87 (+5v_(Input))
/rpi1/CAM0_C_N: J1.8, Module1.140 (CAM0_C_N)
/rpi1/CAM0_C_P: J1.9, Module1.142 (CAM0_C_P)
/rpi1/CAM0_D0_N: J1.2, Module1.128 (CAM0_D0_N)
/rpi1/CAM0_D0_P: J1.3, Module1.130 (CAM0_D0_P)
/rpi1/CAM0_D1_N: J1.5, Module1.134 (CAM0_D1_N)
/rpi1/CAM0_D1_P: J1.6, Module1.136 (CAM0_D1_P)
/rpi1/CAM1_C_N: J2.8, Module1.127 (CAM1_C_N)
/rpi1/CAM1_C_P: J2.9, Module1.129 (CAM1_C_P)
/rpi1/CAM1_D0_N: J2.2, Module1.115 (CAM1_D0_N)
/rpi1/CAM1_D0_P: J2.3, Module1.117 (CAM1_D0_P)
/rpi1/CAM1_D1_N: J2.5, Module1.121 (CAM1_D1_N)
/rpi1/CAM1_D1_P: J2.6, Module1.123 (CAM1_D1_P)
/rpi1/CAM_GPIO: J1.11, J2.11, Module1.97 (Camera_GPIO)
/rpi1/ID_SCL: J2.13, Module1.35 (ID_SC)
/rpi1/ID_SDA: J2.14, Module1.36 (ID_SD)
/rpi1/SCL0: J1.13, Module1.80 (SCL0)
/rpi1/SDA0: J1.14, Module1.82 (SDA0)
GND: J1.1, J1.4, J1.7, J1.10, J2.1, J2.4, J2.7, J2.10, Module1.1 (GND), Module1.2 (GND), Module1.7 (GND), Module1.8 (GND), Module1.13 (GND), Module1.14 (GND), Module1.22 (GND), Module1.23 (GND), Module1.32 (GND), Module1.33 (GND), Module1.42 (GND), Module1.43 (GND), Module1.52 (GND), Module1.53 (GND), Module1.59 (GND), Module1.60 (GND), Module1.65 (GND), Module1.66 (GND), Module1.71 (GND), Module1.74 (GND), Module1.98 (GND), Module1.107 (GND), Module1.108 (GND), Module1.113 (GND), Module1.114 (GND), Module1.119 (GND), Module1.120 (GND), Module1.125 (GND), Module1.126 (GND), Module1.131 (GND), Module1.132 (GND), Module1.137 (GND), Module1.138 (GND), Module1.144 (GND), Module1.150 (GND), Module1.155 (GND), Module1.156 (GND), Module1.161 (GND), Module1.162 (GND), Module1.167 (GND), Module1.168 (GND), Module1.173 (GND), Module1.174 (GND), Module1.179 (GND), Module1.180 (GND), Module1.185 (GND), Module1.186 (GND), Module1.191 (GND), Module1.192 (GND), Module1.197 (GND), Module1.198 (GND)

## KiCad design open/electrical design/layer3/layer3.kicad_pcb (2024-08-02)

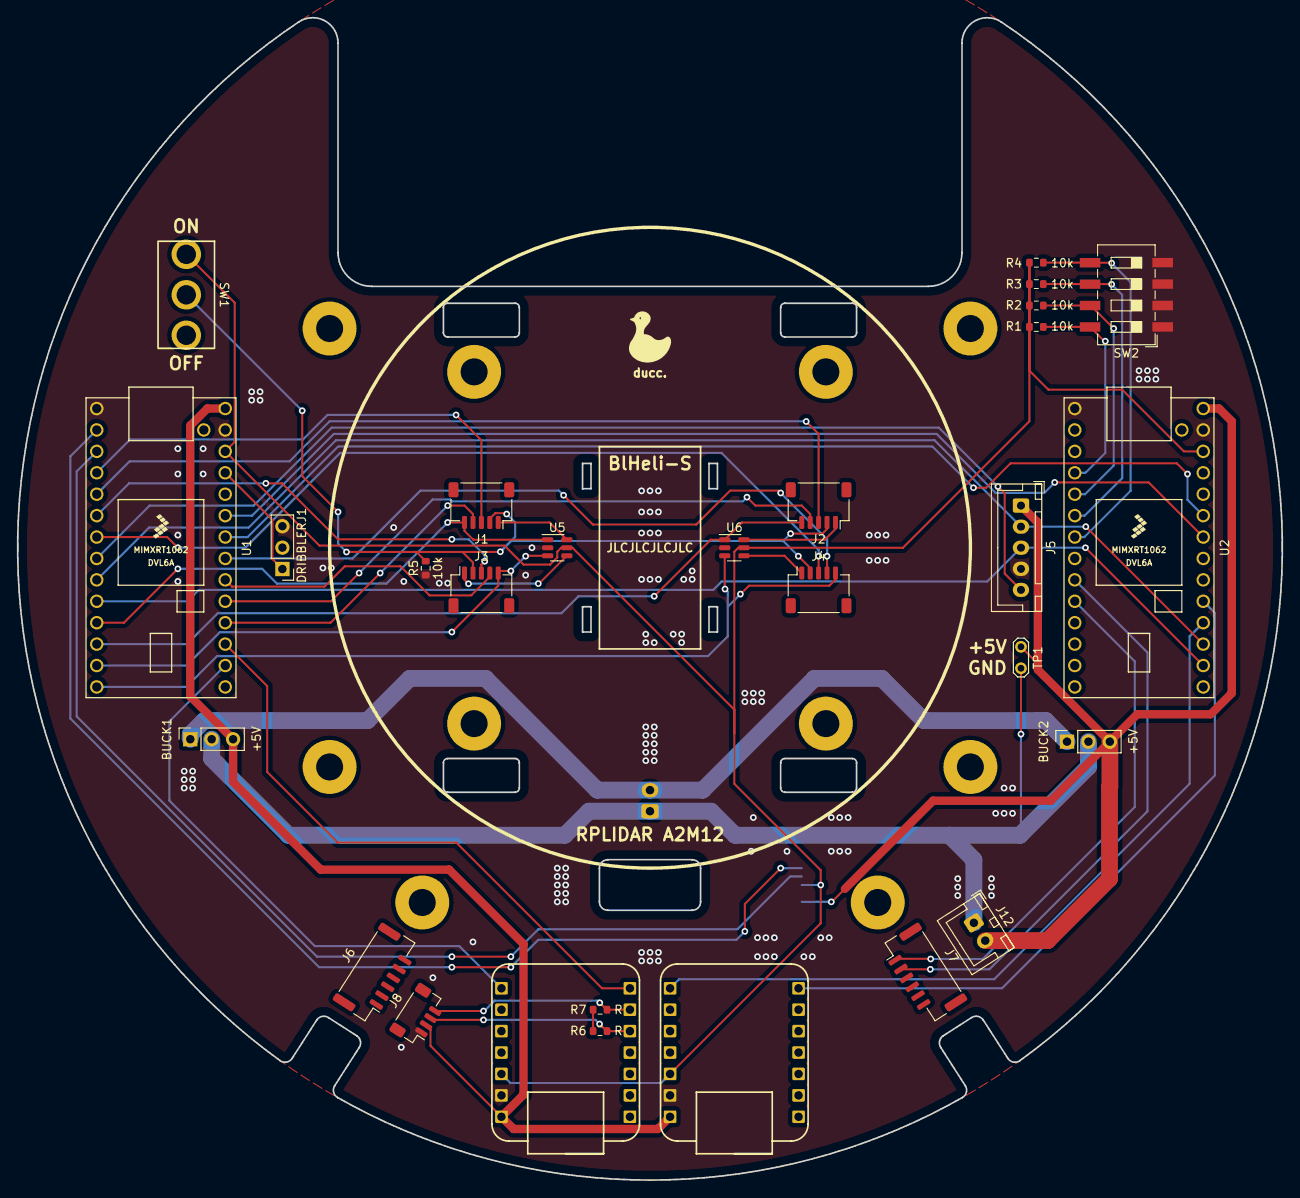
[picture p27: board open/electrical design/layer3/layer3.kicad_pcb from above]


Board: 2 copper layers, 150.0 x 137.9 mm, 41 parts (3 on the bottom side), 45 nets.

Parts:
BUCK1, BUCK2: +5V; TPS5430 Board
DRIBBLERJ1: Conn_01x03_Male; PinHeader_1x03_P2.54mm_Vertical
H1, H2, H3, H4, H5, H6, H7, H8, H9, H10: MountingHole; MountingHole_3.2mm_M3_Pad
J1, J2, J3, J4, J11: SH1.0 5P; JST_SH_SM05B-SRSS-TB_1x05-1MP_P1.00mm_Horizontal
J5: XH2.54 5P; JST_XH_B5B-XH-A_1x05_P2.50mm_Vertical
J6: CAMERA1; JST_GH_BM06B-GHS-TBT_1x06-1MP_P1.25mm_Vertical
J7: CAMERA2; JST_GH_BM06B-GHS-TBT_1x06-1MP_P1.25mm_Vertical
J8: COMPASS; JST_SH_BM04B-SRSS-TB_1x04-1MP_P1.00mm_Vertical
J9, J12: XH2.54 2P; JST_XH_B2B-XH-A_1x02_P2.50mm_Vertical
J10: SH1.0 2P; JST_SH_SM02B-SRSS-TB_1x02-1MP_P1.00mm_Horizontal
R1, R2, R3, R4, R5: 10k; R_0603_1608Metric
R6, R7: R; R_0603_1608Metric
SW1: SW_SPDT; SWITCH_SPDT_PTH_12.7X6.7MM
SW2: SW_DIP_x04; SW_DIP_SPSTx04_Slide_6.7x11.72mm_W8.61mm_P2.54mm_LowProfile
TP1: TestPoint_2Pole; TestPoint_2Pads_Pitch2.54mm_Drill0.8mm
U1, U2: TEENSY 4.0; Teensy40
U3, U4: MOUDLE-SEEEDUINO-XIAO-ESP32C3; xiao-esp32c3
U5, U6: 74LVC2G04; SOT-23-6

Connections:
+3V3: J11.3, R1.1, R2.1, R3.1, R4.1, SW1.1 (A), U1.3.3V_2, U2.3.3V_2, U3.12 (3V3), U4.12 (3V3), U5.5 (VCC), U6.5 (VCC)
+5V: BUCK1.3, BUCK2.3, J5.1, J8.2, J11.1, J12.2, TP1.1, U1.VIN, U2.VIN, U3.14 (5V), U4.14 (5V)
+12V: BUCK1.1, BUCK2.1, J9.2
/BTRX: U2.17, U4.7 (PB08_A6_D6_TX)
/BTTX: U2.16, U4.8 (PB09_A7_D7_RX)
/CAM1RX: J6.1, U2.1
/CAM1TX: J6.2, U2.0
/CAM2RX: J7.1, U2.8
/CAM2TX: J7.2, U2.7
/DRIBBLERPWM: DRIBBLERJ1.1, U1.23
/EN: J1.2, J2.2, J3.2, J4.2, R5.2, SW1.2 (B)
/IMURX: U1.14, U3.8 (PB09_A7_D7_RX)
/IMUSCL: J8.4, R7.1, U3.6 (PA9_A5_D5_SCL)
/IMUSDA: J8.3, R6.1, U3.5 (PA8_A4_D4_SDA)
/IMUTX: U1.15, U3.7 (PB08_A6_D6_TX)
/L1RX: J11.4, U1.1
/L1TX: J11.5, U1.0
/LIDARPWM: J5.5, U1.6
/LIDARRX: J5.3, U1.8, U2.14
/LIDARTX: J5.2, U1.7, U2.15
/M1CS: J1.4, U1.16
/M1INA: J1.5, U1.9, U5.1
/M1INB: J1.1, U5.6
/M1PWM: J1.3, U1.2
/M2CS: J2.4, U1.17
/M2INA: J2.5, U1.10, U6.1
/M2INB: J2.1, U6.6
/M2PWM: J2.3, U1.3
/M3CS: J3.4, U1.18
/M3INA: J3.5, U1.11, U5.3
/M3INB: J3.1, U5.4
/M3PWM: J3.3, U1.4
/M4CS: J4.4, U1.19
/M4INA: J4.5, U1.12, U6.3
/M4INB: J4.1, U6.4
/M4PWM: J4.3, U1.5
/RX: U1.20, U2.21
/STRAT1: R1.2, SW2.8, U2.2
/STRAT2: R2.2, SW2.7, U2.3
/STRAT3: R3.2, SW2.6, U2.4
/STRAT4: R4.2, SW2.5, U2.5
/TX: U1.21, U2.20
GNDD: DRIBBLERJ1.3, J5.4, J8.1, J10.1, J10.2, J11.2, R5.1, SW2.1, SW2.2, SW2.3, SW2.4, U1.G1, U1.G3, U2.G1, U2.G3, U3.13 (GND), U4.13 (GND), U5.2 (GND), U6.2 (GND)
GNDPWR: BUCK1.2, BUCK2.2, J9.1, J12.1, TP1.2
unnamed: R6.2, R7.2

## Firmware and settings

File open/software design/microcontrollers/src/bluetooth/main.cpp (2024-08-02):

/**
 * A BLE client example that is rich in capabilities.
 * There is a lot new capabilities implemented.
 * author unknown
 * updated by chegewara and MoThunderz
 */

#include "main.h"

// TRANSFER to teensy
BtTxDataUnion tx_data;

// receive from other robot
BtRxDataUnion external_rx_data;

// transfer to other robot; RECEIVE from teensy
BtRxDataUnion rx_data;

PacketSerial TeensySerial;

#define BOT1

void onTeensyReceived(const byte *buf, size_t size)
{
    // Read the payload
    BtRxDataUnion data_received;
    // Don't continue if the payload is invalid
    if (size != sizeof(data_received))
        return;
    std::copy(buf, buf + size, std::begin(data_received.bytes));

    rx_data.data.ball_detected = data_received.data.ball_detected;
    rx_data.data.ball_pose = data_received.data.ball_pose;
    rx_data.data.robot_pose = data_received.data.robot_pose;

    // Serial.print("Robot Pose: ");
    // Serial.print(rx_data.data.robot_pose.x);
    // Serial.print(", ");
    // Serial.print(rx_data.data.robot_pose.y);
    // Serial.print(", ");
    // Serial.println(rx_data.data.robot_pose.bearing);
}

#ifdef BOT1
#include "BLEDevice.h"
// #include "BLEScan.h"

// Define UUIDs:
static BLEUUID serviceUUID("d9c3070a-96b8-4053-8115-e3af0af0207f");
static BLEUUID charUUID_1("1ad3eb69-dbe5-496d-a66e-5c3c9cf44d56");
static BLEUUID charUUID_2("66857cb2-b396-44da-99bc-029e6b4731d4");

// Some variables to keep track on device connected
static boolean doConnect = false;
static boolean connected = false;
static boolean doScan = false;
int last_connect_time = 99999999;

// Define pointer for the BLE connection
static BLEAdvertisedDevice *myDevice;
BLERemoteCharacteristic *pRemoteChar_1;
BLERemoteCharacteristic *pRemoteChar_2;

BtTxData txData;
BtRxData rxData;

// Callback function for Notify function
static void notifyCallback(BLERemoteCharacteristic *pBLERemoteCharacteristic,
                           uint8_t *pData,
                           size_t length,
                           bool isNotify)
{
    if (pBLERemoteCharacteristic->getUUID().toString() == charUUID_1.toString())
    {

        // convert received bytes to integer
        uint32_t counter = pData[0];
        for (int i = 1; i < length; i++)
        {
            counter = counter | (pData[i] << i * 8);
        }

        // print to Serial
        Serial.print("Characteristic 1 (Notify) from server: ");
        Serial.println(counter);
    }
}

// Callback function that is called whenever a client is connected or disconnected
class MyClientCallback : public BLEClientCallbacks
{
    void onConnect(BLEClient *pclient)
    {
    }

    void onDisconnect(BLEClient *pclient)
    {
        connected = false;
    }
};

// Function to chech Characteristic
bool connectCharacteristic(BLERemoteService *pRemoteService, BLERemoteCharacteristic *l_BLERemoteChar)
{
    // Obtain a reference to the characteristic in the service of the remote BLE server.
    if (l_BLERemoteChar == nullptr)
    {
        Serial.print("Failed to find one of the characteristics");
        Serial.print(l_BLERemoteChar->getUUID().toString().c_str());
        return false;
    }
    Serial.println(" - Found characteristic: " + String(l_BLERemoteChar->getUUID().toString().c_str()));

    if (l_BLERemoteChar->canNotify())
        l_BLERemoteChar->registerForNotify(notifyCallback);

    return true;
}

// Function that is run whenever the server is connected
bool connectToServer()
{
    Serial.print("Forming a connection to ");
    Serial.println(myDevice->getAddress().toString().c_str());

    BLEClient *pClient = BLEDevice::createClient();
    Serial.println(" - Created client");

    pClient->setClientCallbacks(new MyClientCallback());

    // Connect to the remove BLE Server.
    pClient->connect(myDevice); // if you pass BLEAdvertisedDevice instead of address, it will be recognized type of peer device address (public or private)
    Serial.println(" - Connected to server");

    // Obtain a reference to the service we are after in the remote BLE server.
    BLERemoteService *pRemoteService = pClient->getService(serviceUUID);
    if (pRemoteService == nullptr)
    {
        Serial.print("Failed to find our service UUID: ");
        Serial.println(serviceUUID.toString().c_str());
        pClient->disconnect();
        return false;
    }
    Serial.println(" - Found our service");

    connected = true;
    pRemoteChar_1 = pRemoteService->getCharacteristic(charUUID_1);
    pRemoteChar_2 = pRemoteService->getCharacteristic(charUUID_2);
    if (connectCharacteristic(pRemoteService, pRemoteChar_1) == false)
        connected = false;
    else if (connectCharacteristic(pRemoteService, pRemoteChar_2) == false)
        connected = false;

    if (connected == false)
    {
        pClient->disconnect();
        Serial.println("At least one characteristic UUID not found");
        return false;
    }
    return true;
}

// Scan for BLE servers and find the first one that advertises the service we are looking for.
class MyAdvertisedDeviceCallbacks : public BLEAdvertisedDeviceCallbacks
{
    // Called for each advertising BLE server.
    void onResult(BLEAdvertisedDevice advertisedDevice)
    {
        Serial.print("BLE Advertised Device found: ");
        Serial.println(advertisedDevice.toString().c_str());
        tx_data.data.robot_detected = false;

        // We have found a device, let us now see if it contains the service we are looking for.
        if (advertisedDevice.haveServiceUUID() && advertisedDevice.isAdvertisingService(serviceUUID))
        {

            BLEDevice::getScan()->stop();
            myDevice = new BLEAdvertisedDevice(advertisedDevice);
            doConnect = true;
            doScan = true;

        } // Found our server
    }     // onResult
};        // MyAdvertisedDeviceCallbacks

void setup()
{
#ifdef SERIAL_DEBUG
    Serial.begin(serial_monitor_baud);
    Serial.println("Starting Arduino BLE Client application...");
    BLEDevice::init("");
#endif

    Serial0.begin(bt_serial_baud);
    // Serial0.setTxBufferSize(120);
    // Serial0.setRxBufferSize(120);
    while (!Serial0)
    {
    }
    TeensySerial.setStream(&Serial0);
    TeensySerial.setPacketHandler(&onTeensyReceived);

    // Retrieve a Scanner and set the callback we want to use to be informed when we
    // have detected a new device.  Specify that we want active scanning and start the
    // scan to run for 5 seconds.
    BLEScan *pBLEScan = BLEDevice::getScan();
    pBLEScan->setAdvertisedDeviceCallbacks(new MyAdvertisedDeviceCallbacks());
    pBLEScan->setInterval(1349);
    pBLEScan->setWindow(449);
    pBLEScan->setActiveScan(true);
    pBLEScan->start(5, false);
} // End of setup.

void loop()
{
    TeensySerial.update();
    // If the flag "doConnect" is true then we have scanned for and found the desired
    // BLE Server with which we wish to connect.  Now we connect to it.  Once we are
    // connected we set the connected flag to be true.
    if (doConnect == true)
    {
        if (connectToServer())
        {
            Serial.println("We are now connected to the BLE Server.");
        }
        else
        {
            Serial.println("We have failed to connect to the server; there is nothin more we will do.");
        }
        doConnect = false;
    }

    // If we are connected to a peer BLE Server, update the characteristic each time we are reached
    // with the current time since boot.
    if (connected)
    {
        // std::string rxValue = pRemoteChar_2->readValue();
        uint8_t buff = pRemoteChar_2->readUInt8();
        uint8_t *buf = &buff;

        std::copy(buf, buf + sizeof(buf), std::begin(external_rx_data.bytes));

        tx_data.data.robot_detected = true;
        tx_data.data.ball_detected = external_rx_data.data.ball_detected;
        tx_data.data.ball_pose = external_rx_data.data.ball_pose;
        tx_data.data.robot_pose = external_rx_data.data.robot_pose;

        // Serial.print("Characteristic 2 (readValue): ");
        // Serial.println(rxValue.c_str());
        // Serial.print(tx_data.data.robot_pose.x);
        // Serial.print(", ");
        // Serial.println(tx_data.data.robot_pose.y);

        // String txValue = "String with random value from client: " + String(-random(1000));
        // Serial.println("Characteristic 2 (writeValue): " + txValue);

        // Set the characteristic's value to be the array of bytes that is actually a string.
        pRemoteChar_2->writeValue(rx_data.bytes, sizeof(rx_data.bytes));
    }
    else if (doScan)
    {
        Serial.println("missing data");
        BLEDevice::getScan()->start(0); // this is just example to start scan after disconnect, most likely there is better way to do it in arduino
        tx_data.data.robot_detected = false;
    }

    // tx_data.data.robot_pose.x = 10;
    // tx_data.data.robot_pose.y = 30;

    // Serial.print("Robot Pose: ");
    // Serial.print(tx_data.data.robot_pose.x);
    // Serial.print(", ");
    // Serial.println(tx_data.data.robot_pose.y);
    Serial.println(tx_data.data.robot_detected);
    TeensySerial.send(tx_data.bytes, sizeof(tx_data.bytes));

    // In this example "delay" is used to delay with one second. This is of course a very basic
    // implementation to keep things simple. I recommend to use millis() for any production code
}

#else
#include <BLEDevice.h>
#include <BLEServer.h>
#include <BLEUtils.h>
#include <BLE2902.h>

// Initialize all pointers
BLEServer *pServer = NULL;                   // Pointer to the server
BLECharacteristic *pCharacteristic_1 = NULL; // Pointer to Characteristic 1
BLECharacteristic *pCharacteristic_2 = NULL; // Pointer to Characteristic 2
BLEDescriptor *pDescr_1;                     // Pointer to Descriptor of Characteristic 1
BLE2902 *pBLE2902_1;                         // Pointer to BLE2902 of Characteristic 1
BLE2902 *pBLE2902_2;                         // Pointer to BLE2902 of Characteristic 2

// Some variables to keep track on device connected
bool deviceConnected = false;
bool oldDeviceConnected = false;
int last_write_time = 999999999;

// Variable that will continuously be increased and written to the client
uint32_t value = 0;

// See the following for generating UUIDs:
// https://www.uuidgenerator.net/
// UUIDs used in this example:
#define SERVICE_UUID "d9c3070a-96b8-4053-8115-e3af0af0207f"
#define CHARACTERISTIC_UUID_1 "1ad3eb69-dbe5-496d-a66e-5c3c9cf44d56"
#define CHARACTERISTIC_UUID_2 "66857cb2-b396-44da-99bc-029e6b4731d4"

// Callback function that is called whenever a client is connected or disconnected
class MyServerCallbacks : public BLEServerCallbacks
{
    void onConnect(BLEServer *pServer)
    {
        Serial.println("connected");
        deviceConnected = true;
    };

    void onDisconnect(BLEServer *pServer)
    {
        deviceConnected = false;
        Serial.println("disconnected");
        tx_data.data.robot_detected = false;
        TeensySerial.send(tx_data.bytes, sizeof(tx_data.bytes));
    }
};

class CharacteristicCallBack : public BLECharacteristicCallbacks
{
    void onWrite(BLECharacteristic *pChar) override
    {
        // std::string pChar2_value_stdstr = pChar->getValue();
        // String pChar2_value_string = String(pChar2_value_stdstr.c_str());

        uint8_t *buf = pChar->getData();
        std::copy(buf, buf + sizeof(buf), std::begin(external_rx_data.bytes));

        tx_data.data.robot_detected = true;
        TeensySerial.send(tx_data.bytes, sizeof(tx_data.bytes));
        tx_data.data.ball_detected = external_rx_data.data.ball_detected;
        tx_data.data.ball_pose = external_rx_data.data.ball_pose;
        tx_data.data.robot_pose = external_rx_data.data.robot_pose;

        // Serial.print("Characteristic 2 (readValue): ");
        // Serial.println(rxValue.c_str());
        Serial.println(tx_data.data.robot_detected);

        String txValue = "hello from server";
        uint8_t identify = 36;
        uint8_t *identifier = &identify;
        pCharacteristic_2->setValue(identifier, sizeof(identifier));
        last_write_time = millis();
    }
};

void setup()
{
#ifdef SERIAL_DEBUG
    Serial.begin(serial_monitor_baud);
#endif

    Serial0.begin(bt_serial_baud);
    // Serial0.setTxBufferSize(120);
    // Serial0.setRxBufferSize(120);
    while (!Serial0)
    {
    }
    TeensySerial.setStream(&Serial0);
    TeensySerial.setPacketHandler(&onTeensyReceived);

    // Create the BLE Device
    BLEDevice::init("ESP32");

    // Create the BLE Server
    pServer = BLEDevice::createServer();
    pServer->setCallbacks(new MyServerCallbacks());

    // Create the BLE Service
    BLEService *pService = pServer->createService(SERVICE_UUID);

    // Create a BLE Characteristic
    pCharacteristic_1 = pService->createCharacteristic(
        CHARACTERISTIC_UUID_1,
        BLECharacteristic::PROPERTY_NOTIFY);

    pCharacteristic_2 = pService->createCharacteristic(
        CHARACTERISTIC_UUID_2,
        BLECharacteristic::PROPERTY_READ |
            BLECharacteristic::PROPERTY_WRITE |
            BLECharacteristic::PROPERTY_NOTIFY);

    // Create a BLE Descriptor
    pDescr_1 = new BLEDescriptor((uint16_t)0x2901);
    pDescr_1->setValue("A very interesting variable");
    pCharacteristic_1->addDescriptor(pDescr_1);

    // Add the BLE2902 Descriptor because we are using "PROPERTY_NOTIFY"
    pBLE2902_1 = new BLE2902();
    pBLE2902_1->setNotifications(true);
    pCharacteristic_1->addDescriptor(pBLE2902_1);

    pBLE2902_2 = new BLE2902();
    pBLE2902_2->setNotifications(true);
    pCharacteristic_2->addDescriptor(pBLE2902_2);

    // add callback functions here:
    pCharacteristic_2->setCallbacks(new CharacteristicCallBack());

    // Start the service
    pService->start();

    // Start advertising
    BLEAdvertising *pAdvertising = BLEDevice::getAdvertising();
    pAdvertising->addServiceUUID(SERVICE_UUID);
    pAdvertising->setScanResponse(false);
    pAdvertising->setMinPreferred(0x0); // set value to 0x00 to not advertise this parameter
    BLEDevice::startAdvertising();
    Serial.println("Waiting a client connection to notify...");
}

void loop()
{
    TeensySerial.update();

    // The code below keeps the connection status uptodate:
    // Disconnecting
    if (!deviceConnected && oldDeviceConnected)
    {
        delay(500);                  // give the bluetooth stack the chance to get things ready
        pServer->startAdvertising(); // restart advertising
        // Serial.println("start advertising");
        oldDeviceConnected = deviceConnected;
    }
    // Connecting
    if (deviceConnected && !oldDeviceConnected)
    {
        // do stuff here on connecting
        oldDeviceConnected = deviceConnected;
    }

    tx_data.data.ball_pose.x = 10;
    tx_data.data.ball_pose.y = 30;

    if (millis() - last_write_time > 1000)
    {
        tx_data.data.robot_detected = false;
        TeensySerial.send(tx_data.bytes, sizeof(tx_data.bytes));
        // Serial.println("No data received from client");
    }
}
#endif

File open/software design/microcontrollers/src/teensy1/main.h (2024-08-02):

#pragma once

#ifndef MAIN_H
#define MAIN_H

// #define DEBUG
// #define SERIAL_DEBUG
#define BOT1

#include <common.h>

#define DRIBBLER_LOWER_LIMIT 32
#define DRIBBLER_UPPER_LIMIT 48

#ifdef BOT1
#define FL_PWM 3
#define FR_PWM 2
#define BL_PWM 4
#define BR_PWM 5
#define LIDAR_PWM 6
#define DRIBBLER_PWM 23

#define FL_INA 10
#define FR_INA 9
#define BL_INA 11
#define BR_INA 12

#else

#define FL_PWM 2
#define FR_PWM 3
#define BL_PWM 4
#define BR_PWM 5
#define LIDAR_PWM 6
#define DRIBBLER_PWM 23

#define FL_INA 9
#define FR_INA 10
#define BL_INA 11
#define BR_INA 12

#endif

#define FL_CS 17
#define FR_CS 16
#define BL_CS 18
#define BR_CS 19

class Base
{
public:
    void setUp();
    void move(double vel, double angle, double bearing, double kp = 0.0013, double ki = 0.0, double kd = 0.005, double ema_constant = 0.02);
    void motorOut(int motor, double speed);
    double getAggregateSpeed(int motor);

    const double wheel_angle = 50 * M_PI / 180.0;
    const int max_pwm = 8192;
    const int min_speed = 800;
    // const double ema_constant = 0.0002;

    const double fl_voltage = 2.500;
    const double fr_voltage = 2.300;
    const double bl_voltage = 2.282;
    const double br_voltage = 2.480;
    const double fastest_motor = fl_voltage;

    // const double fl_scale = fastest_motor / fl_voltage;
    // const double fr_scale = fastest_motor / fr_voltage;
    // const double bl_scale = fastest_motor / bl_voltage;
    // const double br_scale = fastest_motor / br_voltage;

    const int fl_scale = 1;
    const int fr_scale = 1;
    const int bl_scale = 1;
    const int br_scale = 1;

    double prev_fl_out = 0;
    double prev_fr_out = 0;
    double prev_bl_out = 0;
    double prev_br_out = 0;
};

struct MoveData
{
    double speed;
    double target_angle;
    double target_bearing;
    double ema_constant;
};

struct LineData
{
    bool on_line;
    bool already_on_line;

    double initial_line_angle;
    double line_angle;
    int chord_length;
    double line_centre;

    float line_start_ldr;
    float line_end_ldr;

    float ldr_angles[15][32] = {
        {
            318.43,
            324.19,
            329.99,
            335.86,
            341.87,
            348.16,
            355.30,
            8.36,
            171.64,
            184.70,
            191.84,
            198.13,
            204.14,
            210.01,
            215.81,
            221.57,
            227.31,
            233.03,
            238.73,
            244.42,
            250.11,
            255.80,
            261.48,
            267.16,
            272.84,
            278.52,
            284.20,
            289.89,
            295.58,
            301.27,
            306.97,
            312.69,
        },
        {
            320.31,
            326.49,
            332.84,
            339.47,
            346.62,
            354.91,
            6.50,
            36.04,
            143.96,
            173.50,
            185.09,
            193.38,
            200.53,
            207.16,
            213.51,
            219.69,
            225.76,
            231.76,
            237.70,
            243.62,
            249.50,
            255.37,
            261.23,
            267.08,
            272.92,
            278.77,
            284.63,
            290.50,
            296.38,
            302.30,
            308.24,
            314.24,
        },
        {
            323.61,
            330.51,
            337.79,
            345.70,
            354.74,
            6.11,
            23.38,
            59.09,
            120.91,
            156.62,
            173.89,
            185.26,
            194.30,
            202.21,
            209.49,
            216.39,
            223.04,
            229.53,
            235.91,
            242.20,
            248.43,
            254.62,
            260.78,
            266.93,
            273.07,
            279.22,
            285.38,
            291.57,
            297.80,
            304.09,
            310.47,
            316.96,
        },
        {
            328.53,
            336.46,
            345.04,
            354.63,
            5.93,
            20.35,
            40.72,
            71.21,
            108.79,
            139.28,
            159.65,
            174.07,
            185.37,
            194.96,
            203.54,
            211.47,
            218.97,
            226.19,
            233.19,
            240.05,
            246.80,
            253.48,
            260.10,
            266.70,
            273.30,
            279.90,
            286.52,
            293.20,
            299.95,
            306.81,
            313.81,
            321.03,
        },
        {
            335.31,
            344.51,
            354.55,
            5.82,
            18.92,
            34.70,
            54.12,
            77.43,
            102.57,
            125.88,
            145.30,
            161.08,
            174.18,
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

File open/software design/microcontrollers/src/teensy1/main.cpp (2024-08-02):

#include "main.h"
#include "HardwareSerial.h"

PacketSerial Layer1Serial;
PacketSerial ImuSerial;
PacketSerial TeensySerial;

Layer1RxDataUnion layer_1_rx_data;
ImuRxDataUnion imu_rx_data;
Teensy1TxDataUnion teensy_1_tx_data;

Robot robot;
Ball ball;
Goal yellow_goal;
Goal blue_goal;

unsigned long last_time = 0;
int real = 0;
int points = 0;

int ball_catchment = 0;

// #define DEBUG

unsigned long time_ball_stopped;
double ball_last_dist;
bool was_goalie_now_striker;
bool is_goalie;

void striker()
{
  if (!ball.detected)
  {
    robot.task = 0;
  }
  else
  {
    if (ball.distance_from_robot > 100)
    {
      robot.task = 0;
    }
    else if (abs(ball.current_pose.bearing - blue_goal.current_pose.bearing) < 30)
    {
      robot.task = 1;
    }
    else
    {
      robot.task = 0;
    }

    if (ball.distance_from_robot > 500)
    {
      robot.dribbler.dribbling = false;
    }
    else
    {
      robot.dribbler.dribbling = true;
    }
  }
}

void soloGoalie()
{
  if (ball_last_dist - ball.distance_from_robot > 200)
  {
    time_ball_stopped = millis();
  }

  ball_last_dist = ball.distance_from_robot;

  // Serial.print("time ball stopped: ");
  // Serial.println(time_ball_stopped);

  if (millis() - time_ball_stopped > 1000 && ball.distance_from_robot < 500 && !was_goalie_now_striker)
  {
    robot.task = 0;
    was_goalie_now_striker = true;
  }
  // else if (ball.detected && ball.current_pose.y < 0)
  // {
  //   robot.task = 0;
  //   was_goalie_now_striker = true;
  // }
  else if (was_goalie_now_striker && robot.current_pose.y < 700)
  {
    robot.task = 0;
  }
  else
  {
    robot.task = 2;
    was_goalie_now_striker = false;
  }
}

void setup()
{
  robot.base.setUp();
  robot.setUpSerial();
  pinModeFast(DRIBBLER_PWM, OUTPUT);
  pinModeFast(LIDAR_PWM, OUTPUT);

  robot.previous_pose.x = 0;
  robot.previous_pose.y = 0;
  robot.previous_pose.bearing = 0;

  last_time = millis();
  robot.dribbler.update();
  robot.dribbler.dribbling = true;
}

void loop()
{
  robot.updateSerial();
  robot.sendSerial();

  if (ball.in_catchment || (ball.detected && ball.distance_from_robot < 1000))
  {
    robot.dribbler.dribbling = true;
  }
  else
  {
    robot.dribbler.dribbling = false;
  }

  if (ball.in_catchment)
  {
    // Serial.println("Ball in catchment");
    ++ball_catchment;
  }
  else
  {
    ball_catchment = 0;
  }

  double flick_angle = 0;
  double kp = 0.0014;
  double ki = 0.0;
  double kd = 0.005;

  // if (ball_catchment > 100)
  // {
  //   robot.target_pose = robot.current_pose.x - 910 > 0 ? Pose({1430, 1785, 180}) : Pose({520, 1785, 180});
  //   flick_angle = robot.current_pose.x - 910 > 0 ? 270 : 90;
  //   kp = robot.current_pose.x - 910 > 0 ? 0.01 : 0.1;
  //   double dist_from_target = sqrt(pow(robot.current_pose.x - robot.target_pose.x, 2) + pow(robot.current_pose.y - robot.target_pose.y, 2));
  //   Serial.println(dist_from_target);
  //   if (dist_from_target < 400)
  //   {
  //     robot.task = 1;
  //   }
  //   else
  //     robot.task = 3;
  // }
  // else if (ball.detected)
  // {
  //   if (ball.current_pose.y < 0)
  //   {
  //     robot.task = 2;
  //   }
  //   else
  //   {
  //     robot.task = 0;
  //   }
  // }
  // else
  // {
  //   robot.task = 2;
  //

#ifndef BOT1
  // pure goalie code
  if (!robot.alliance_robot_detected)
  {
    if (robot.dip_1_on)
    {
      striker();
    }
    else
    {
      soloGoalie();
    }
  }
  else
  {
    if (robot.dip_2_on)
    {
      striker();
    }
    else
    {
      robot.task = 2;
    }
  }

#else
  // pure striker code
  striker();
  // if (!robot.alliance_robot_detected && ball.current_pose.y < 700)
  // {
  //   soloGoalie();
  // }
  // else
  // {
  //   striker();
  // }
#endif

  // robot.task = 2;
  // robot.task = 0;

  // if (is_goalie && ball.distance_from_robot < 500)
  // {
  //   robot.task = 0;
  //   is_goalie = false;
  // }
  // else if (!is_goalie && robot.current_pose.y < 1000)
  // {
  //   robot.task = 0;
  //   is_goalie = false;
  // }
  // else
  // {
  //   robot.task = 2;
  //   is_goalie = true;
  // }

  // Serial.print("task: ");
  // Serial.println(robot.task);

  switch (robot.task)
  {
  case 0:
    robot.orbitToBall(0);
    // robot.rotateToBall();
    break;
  case 1:
    // robot.move_data.speed = 0;
    // robot.move_data.target_bearing = flick_angle;
    // robot.move_data.target_angle = 0;
    robot.orbitScore();
    break;
  case 2:
    robot.defendGoal();
    break;
  case 3:
    kp = 0.0013;
    robot.moveToTargetPose();
    break;
  }

  // Serial.print("task");
  // Serial.println(robot.task);

  robot.dribbler.dribbling = true;
  robot.dribbler.update();

  robot.base.move(robot.move_data.speed, robot.move_data.target_angle, robot.move_data.target_bearing, kp, ki, kd);
  // robot.base.move(0.6, 0, 0, kp, ki, kd);
}

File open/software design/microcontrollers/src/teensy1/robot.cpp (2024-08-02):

#include "main.h"

double prev_distance = 0;

void Robot::moveToTargetPose()
{
    double x_diff = target_pose.x - current_pose.x;
    double y_diff = target_pose.y - current_pose.y;
    double angle_diff = atan2(x_diff, y_diff);
    double actual_angle_diff = correctBearing(degrees(angle_diff) - current_pose.bearing);

    double distance = sqrt(pow(x_diff, 2) + pow(y_diff, 2));

    // Serial.print(x_diff);
    // Serial.print(" ");
    // Serial.print(y_diff);
    // Serial.print(" ");
    // Serial.println(actual_angle_diff);

    double speed = fmin(0.0005 * distance + 0.0008 * (distance - prev_distance), 0.4);

    // Serial.println(target_pose.bearing);

    move_data.speed = speed;
    move_data.target_angle = correctBearing(actual_angle_diff);
    move_data.target_bearing = correctBearing(target_pose.bearing);
    move_data.ema_constant = 0.0002;
    prev_distance = distance;
}

void Robot::trackLine(double speed, double angle, int offset)
{
    double correction = 0;

    offset = angle > 180 ? offset : -offset;

    double ldr_start_angle = line_data.ldr_angles[7 + offset][31 - (int)line_data.line_start_ldr] + current_pose.bearing;
    double ldr_end_angle = line_data.ldr_angles[7 + offset][31 - (int)line_data.line_end_ldr] + current_pose.bearing;

    double ldr_start_correct_angle = correctBearing(angle - ldr_start_angle);
    double ldr_end_correct_angle = correctBearing(angle - ldr_end_angle);

    if (ldr_start_correct_angle > 180)
    {
        ldr_start_correct_angle -= 360;
    }
    else if (ldr_start_correct_angle < -180)
    {
        ldr_start_correct_angle += 360;
    }

    if (ldr_end_correct_angle > 180)
    {
        ldr_end_correct_angle -= 360;
    }
    else if (ldr_end_correct_angle < -180)
    {
        ldr_end_correct_angle += 360;
    }

    if (abs(ldr_start_correct_angle) < abs(ldr_end_correct_angle))
    {
        correction = ldr_start_angle;
    }
    else
    {
        correction = ldr_end_angle;
    }

    move_data.speed = speed;
    move_data.target_angle = correctBearing(correction);
    move_data.target_bearing = 0;
    move_data.ema_constant = 0.0002;
}

void Robot::rejectLine(double bearing)
{
    move_data.speed = 0.03 * line_data.chord_length;
    move_data.target_angle = correctBearing(line_data.line_angle + 180);
    move_data.target_bearing = bearing;
    move_data.ema_constant = 0.005;
}

void Robot::trackLineGoalie(double speed, double angle, int offset)
{
    double correction = 0;

    offset = angle > 180 ? offset : -offset;

    double ldr_start_angle = line_data.ldr_angles[7 + offset][31 - (int)line_data.line_start_ldr] + current_pose.bearing;
    double ldr_end_angle = line_data.ldr_angles[7 + offset][31 - (int)line_data.line_end_ldr] + current_pose.bearing;

    double ldr_start_correct_angle = correctBearing(angle - ldr_start_angle);
    double ldr_end_correct_angle = correctBearing(angle - ldr_end_angle);

    if (ldr_start_correct_angle > 180)
    {
        ldr_start_correct_angle -= 360;
    }
    else if (ldr_start_correct_angle < -180)
    {
        ldr_start_correct_angle += 360;
    }

    if (ldr_end_correct_angle > 180)
    {
        ldr_end_correct_angle -= 360;
    }
    else if (ldr_end_correct_angle < -180)
    {
        ldr_end_correct_angle += 360;
    }

    if (abs(ldr_start_correct_angle) < abs(ldr_end_correct_angle))
    {
        correction = correctBearing(ldr_start_angle);
    }
    else
    {
        correction = correctBearing(ldr_end_angle);
    }

    // if (correctBearing(correction) < 165 || correctBearing(correction) > 195)
    // {
    //     move_data.speed = speed;
    //     move_data.target_angle = correctBearing(correction);
    //     move_data.target_bearing = 0;
    // }
    // else
    // {
    //     move_data.speed = 0;
    //     move_data.target_angle = 0;
    //     move_data.target_bearing = 0;
    // }

    if (abs(correction - 180) < 20)
    {
        move_data.speed = 0;
        move_data.target_angle = correction - 180 > 0 ? 130 : 230;
        move_data.target_bearing = 0;
        move_data.ema_constant = 0.0002;
    }
    else
    {
        move_data.speed = speed;
        move_data.target_angle = correctBearing(correction);
        move_data.target_bearing = 0;
        move_data.ema_constant = 0.0002;
    }
}

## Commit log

2023-10-21 add layer 1 shroud files
    [layer 1 cover (back).stl, layer 1 cover (front left).stl, layer 1 cover (front right).stl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]
2023-10-21 add dribbler files
    [gear cover.stl, gear shield (3mm gear).stl, gear shield (5mm gear).stl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]
2023-10-21 add cycloidal gearbox files
    [disc 1.stl, disc 2.stl, eccentric mount.stl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]
2023-11-01 start work on layer 1 pcb
    [layer1.kicad_pcb, layer1.kicad_sch]
2023-11-01 add layer 2, 3, and 4 pcb files
    [cam1.kicad_sch, layer2.kicad_pcb, layer2.kicad_sch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]
2023-11-01 add omniwheel mesh files
    [layer 1.stl, layer 2.stl, layer 3.stl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]
2023-11-01 update dribbler mesh files
    [dribbler mount.stl, gear cover.stl, gear shield (5mm gear).stl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]
2023-11-01 update cycloidal drive mesh files
    [disc 1.stl, disc 2.stl, eccentric mount.stl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]
2023-11-01 add layer 1 drawings
    [full drawing.dxf, outline.dxf, screw holes.dxf]
2023-11-19 update layer 1 pcb
    [layer1.kicad_pcb, layer1.kicad_sch, layer3.kicad_sch]
2023-11-19 update layer 2 pcb
    [layer2.kicad_pcb, layer2.kicad_sch]
2023-11-19 update layer 3 pcb
    [layer3.kicad_pcb]
2023-11-19 update layer 4 pcb
    [layer4.kicad_pcb]
2023-11-19 include new kicad libraries and vnh5019 pcb
    [vnh5019.kicad_pcb, vnh5019.kicad_sch]
2023-11-19 updated pcb plate drawings
    [driver.dxf, full drawing.dxf, full outline.dxf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]
2023-11-19 update pcb plate drawings
    [driver.dxf, full drawing.dxf, full outline.dxf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]
2023-11-20 placed layer 1 mounting holes
    [layer1.kicad_pcb]
2023-11-20 placed layer 2 mth
    [layer2.kicad_pcb]
2023-11-22 add boost to l1 pcb and update mech drawing
    [full drawing.dxf, layer1.kicad_pcb, layer1.kicad_sch]
2023-11-22 routed l1 mux
    [layer1.kicad_pcb]
2023-11-23 route l1 signal lines and resolve drc issues
    [layer1.kicad_pcb, layer1.kicad_sch]
2023-11-23 add XIAO and teensy footprint drawings
    [drawing.dxf]
2023-11-23 update layer 1 pcb drawing
    [outline.dxf]
2023-11-23 update layer 2 pcb drawing
    [layer2.kicad_pcb, outline.dxf]
2023-11-24 reposition kicker circuit and improve routing
    [layer1.kicad_pcb, layer1.kicad_sch]
2023-12-14 change driver output connector to 5 pins
    [vnh5019.kicad_pcb, vnh5019.kicad_sch]
2023-12-14 update layer 1 design files
    [layer1.kicad_pcb, layer1.kicad_sch]
2023-12-14 add connectors for power transfer to l3
    [layer2.kicad_pcb, layer2.kicad_sch]
2023-12-14 lay out components on l3
    [layer3.kicad_pcb, layer3.kicad_sch]
2023-12-14 update pcbs and mech drawings
    [full drawing.dxf, layer1.kicad_pcb, layer2.kicad_pcb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]
2023-12-15 mostly finalise pcb drawings for pre-fab
    [fabrication drawing.dxf, full drawing.dxf]
2023-12-15 update l2 pcb with additional batt connectors
    [layer2.kicad_pcb, layer2.kicad_sch]
2023-12-15 routed layer 3
    [layer3.kicad_pcb]
2023-12-15 update pcbs for dual camera design
    [layer1.kicad_pcb, layer2.kicad_pcb, layer2.kicad_sch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]
2023-12-16 add indicator leds to driver pcb
    [vnh5019.kicad_pcb, vnh5019.kicad_sch]
2023-12-16 change EN switch to larger one
    [layer3.kicad_pcb, layer3.kicad_sch]
2023-12-16 add fb between vccq and 3v3
    [layer1.kicad_pcb, layer1.kicad_sch]
2023-12-16 route layer 3
    [layer3.kicad_pcb]
2023-12-16 add pwm pullup resistor to rpi fan connector
    [layer2.kicad_pcb, layer2.kicad_sch]
2023-12-16 add 5v test point on l3
    [layer3.kicad_pcb, layer3.kicad_sch]
2023-12-16 amend buck conv pinouts on l1 and l3
    [layer1.kicad_pcb, layer1.kicad_sch, layer3.kicad_pcb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]
2023-12-17 update l3 pcb with new board outline
    [layer3.kicad_pcb, outline.dxf]
2023-12-17 reposition motor power ports
    [layer2.kicad_pcb, layer2.kicad_sch]
2023-12-17 resolve some l2 and l3 board issues
    [layer2.kicad_pcb, layer3.kicad_pcb]
2023-12-17 add jlc order number silkscreen
    [layer1.kicad_pcb, layer2.kicad_pcb, layer3.kicad_pcb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]
2023-12-18 reroute 90 deg traces on l3 pcb
    [layer3.kicad_pcb, layer3.kicad_sch]
2023-12-18 add ducc finishes and route unconnected l3 items
    [layer1.kicad_pcb, layer2.kicad_pcb, layer3.kicad_pcb]
2023-12-24 finalise pcbs for production
    [full drawing.dxf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]
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2024-01-01 correct led inductor value
    [layer1.kicad_pcb, layer1.kicad_sch]
2024-01-01 implement ema + serial and correct syntax errors
    [base.cpp, lidar.cpp, main.cpp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]
2024-01-02 correct reversed buck layout on l1 pcb
    [layer1.kicad_pcb, layer1.kicad_sch]
2024-01-11 mostly working line avoidance
    [base.cpp, lidar.cpp, light_ring.cpp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]
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2024-01-16 layer 1 lw pcb
    [clasp.stl, dribbler mount v29.stl, gear cover.stl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]
2024-01-17 moved boost cirvcuit on lw layer 1
    [layer1.kicad_pcb]
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2024-01-24 reorg folders; added cura profile
    [cam1.kicad_sch, clasp.stl, drawing.dxf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]
2024-01-25 stl files for dribbler
    [clasp.stl, gear shield.stl, plate (left).stl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]
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2024-01-29 reinstate open elec files
    [cam1.kicad_sch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]
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2024-02-19 remove elec files, update mech files, update code
    [battery plate adapter.stl, big mould (left).stl, big mould (right).stl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]
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2024-02-20 fix layer 1 corrupted files; re-format folder
    [ir.kicad_sch, layer 3.dxf, layer1.kicad_pcb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]
2024-02-20 move stuff around layer 3; add stm32 prog switch
    [ir.kicad_sch, layer3.kicad_pcb]
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2024-02-21 add new dribbler moulds
    [big mould (left).stl, big mould (right).stl, big mould (top).stl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]
2024-02-21 update lw l3 pcb
    [ir.kicad_sch, layer1.kicad_pcb, layer1.kicad_sch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]
2024-02-21 resolve pcb merge conflicts
    [layer3.kicad_pcb]
2024-02-22 fix drc faults on l1, l2, and l3 pcbs
    [layer1.kicad_pcb, layer1.kicad_sch, layer3.kicad_pcb]
2024-03-14 fix line approach angle calc
    [light_ring.cpp]
2024-03-19 add lw pcb files
    [layer 3.dxf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]
2024-03-19 add open mech drawings
    [housing.stl, layer 1 short cover.stl, layer 4.5.dxf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]
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2024-03-28 fix lidar transfer bugs, working orbit code
    [base.cpp, lidar.cpp, main.cpp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]
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2024-05-06 rerouted lw l3 ir stm circuit
    [gear shield.stl, ir.kicad_sch, layer3.kicad_pcb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]
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

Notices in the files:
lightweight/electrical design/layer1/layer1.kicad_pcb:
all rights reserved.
